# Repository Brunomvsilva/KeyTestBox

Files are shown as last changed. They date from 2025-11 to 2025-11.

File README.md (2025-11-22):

# KeytestBox

_Embedded platform designed to integrate automotive HMI key-testing systems in production environments._

_This project was developed at Preh Portugal as part of my Master’s thesis._

---

## Preview

<table align="center">
  <tr>
    <td align="center">
      Real PCB Photo<br>
      <em>Real KeytestBox Image</em>
    </td>
    <td align="center">
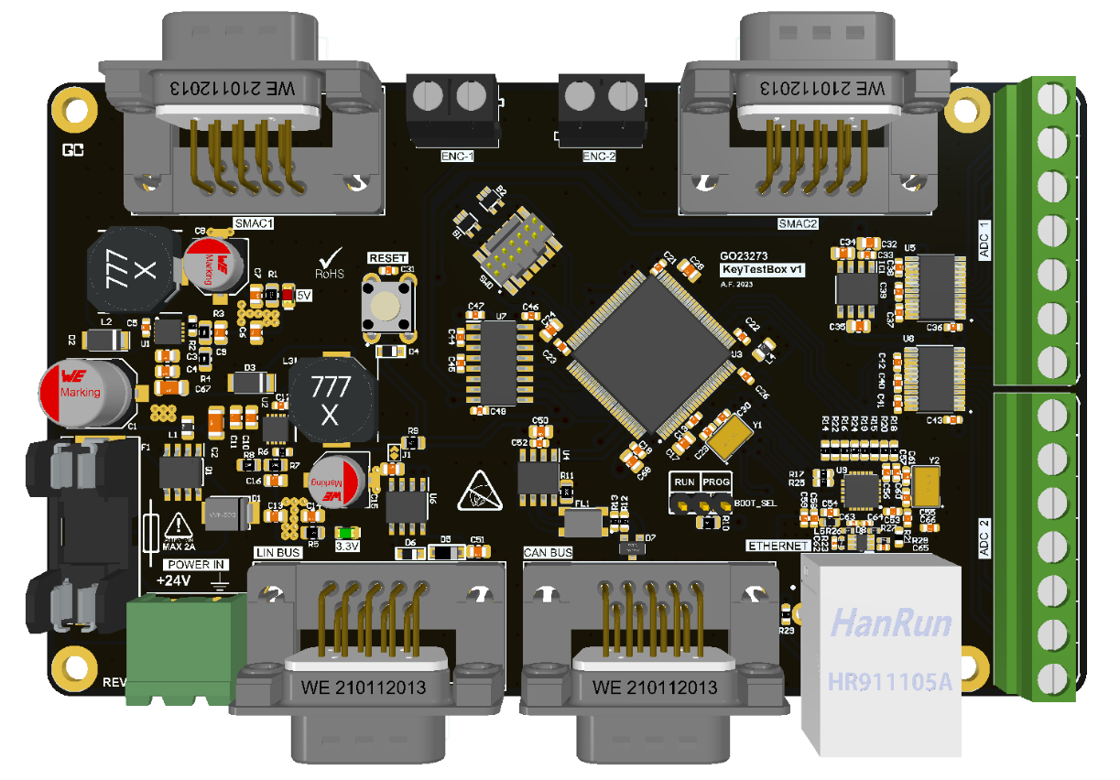
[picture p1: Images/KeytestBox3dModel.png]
3D Model of KeyTestBox
      <br>
      <em>3D model of the KeyTestBox enclosure</em>
    </td>
  </tr>
</table>

---

## Table of Contents

- [Introduction](#introduction)
- [Typical Key Test Output](#typical-key-test-output)
- [Incremental vs Continuous Tests](#incremental-vs-continuous-tests)
  - [Incremental Tests](#incremental-tests)
  - [Continuous Tests](#continuous-tests)
- [Problem Statement](#problem-statement)
  - [Problem 1: Delay via CAN/LIN](#problem-1-delay-when-reading-uut-data-via-can-or-lin)
  - [Problem 2: Low resolution and missed events](#problem-2-low-resolution-and-missed-events-in-incremental-tests)
  - [Consequence](#consequence-forced-to-use-expensive-continuous-test-systems)
- [Solution, Main Goals and Requirements](#solution-main-goals-and-requirements)
  - [Main Goals](#main-goals)
  - [Hardware Requirements](#hardware-requirements)
  - [Software Requirements](#software-requirements)
- [Hardware Overview](#hardware-overview)
- [Final Hardware](#final-hardware)
- [Software and Tools Used](#software-and-tools-used)
- [MQTT Commands Implemented](#mqtt-commands-implemented)
- [Tests and Results](#tests-and-results)
  - [UUT Lever and Testbench Setup](#uut-lever-test-and-testbench-setup)
  - [Sampling and Performance](#sampling-and-performance)
- [Conclusion](#conclusion)
- [Skills Learned](#skills-learned)

---

## Introduction 

Automotive HMI, such as climate and central control panels, rely on high-quality tactile feedback. **Force–displacement** key tests quantify that feel essencially by measuring the relation between **applied force** and **key travel**.

Images below display the **main components** of a key test system

<div align="center">
<table>
  <tr>
    <td style="padding-right: 40px;">
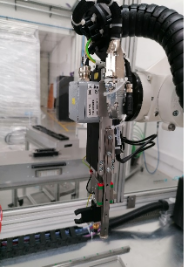
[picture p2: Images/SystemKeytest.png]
      
    </td>
    <td style="padding-left: 40px;">
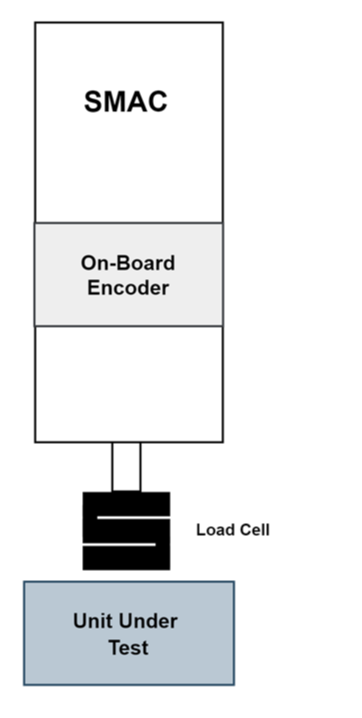
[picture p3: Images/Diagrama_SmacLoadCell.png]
      
    </td>
  </tr>
</table>
</div>

### During a test:
- The key is pressed by a **SMAC linear motor**  
- **Force** is measured using a **load cell with an amplifier**  
- **Key travel (displacement)** is obtained from the **SMAC internal encoder**  
- The **Unit Under Test (UUT)** sends data via **CAN/LIN** during the test, such as:  
  - **Key state (pressed / released)**
  - **Lever position or angle** (e.g. gear selector tests)  
  - **Selected gear value**  
  - **UUT Hall sensors or internal position data**  
  - Other diagnostic or status information

### Typical Key Test Output

The **Force–Displacement** curve is the most common way to characterize how a key or button behaves when it is pressed and released. It represents the force applied to the key as a function of its travel (displacement).

<p align="center">
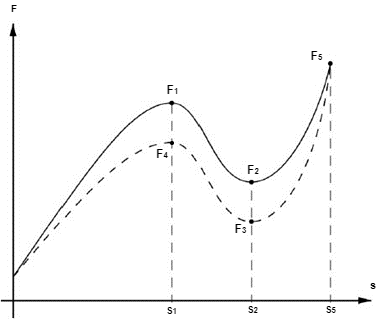
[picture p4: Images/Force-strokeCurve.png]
  
</p>

Curves differ depending on the type of key being tested.
During a test, the key is pressed (force increases) until it reaches a maximum point, and then released. From this curve, mechanical parameters of the key can be extracted:

| Symbol | Description |
|---|---|
| **S1** | Displacement at which the key actuates (snap/collapse point). |
| **F1** | Actuation force – force required to trigger the snap of the membrane or key mechanism at S1. |
| **S2** | Displacement where electrical contact occurs with the PCB. |
| **F2** | Contact force – minimum force required to close the electrical contact at S2. |
| **F3** | Return force – force at which the electrical contact is released during the return movement. |
| **F4** | Force difference between actuation and release states. |
| **F5** | Maximum applied force during the test (should not exceed mechanical limits). |
| **Ss** | Maximum travel / end of mechanical stroke. |

One of the most important metrics derived from this curve is the **Snap Ratio (SR)**, which indicates how strong the tactile feedback is:

$$
SR=\dfrac{F_1-F_2}{F_1}\times 100\%
$$

- A higher **Snap Ratio** = stronger tactile feedback (more noticeable “click”).
- A lower **Snap Ratio** = softer feedback, which may feel smoother but less perceptible.
- Ideal **SR** values depend on the application.

---

## Incremental vs Continuous Tests

The flowcharts below provide a simplified comparison between the two testing methods.  
The main difference is that in **Incremental Tests**, the actuator stops at each step to acquire a sample, while in **Continuous Tests**, the actuator moves without stopping and data is sampled in real time.

<table align="center">
  <tr>
    <td align="center">
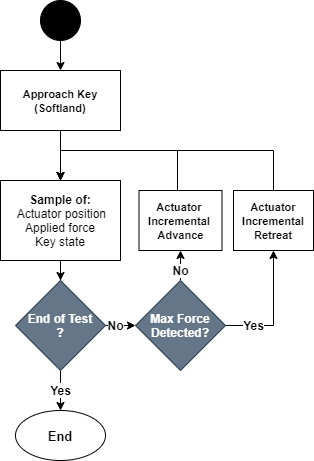
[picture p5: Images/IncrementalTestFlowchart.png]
      <br>
      <em>Incremental Test Flowchart</em>
    </td>
    <td align="center">
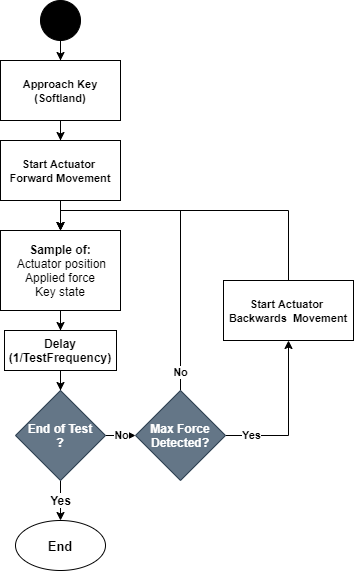
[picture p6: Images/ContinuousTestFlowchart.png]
      <br>
      <em>Continuous Test Flowchart</em>
    </td>
  </tr>
</table>

---

## Incremental Tests

### Incremental Test System Example (without the KeyTestBox)

<p align="center">
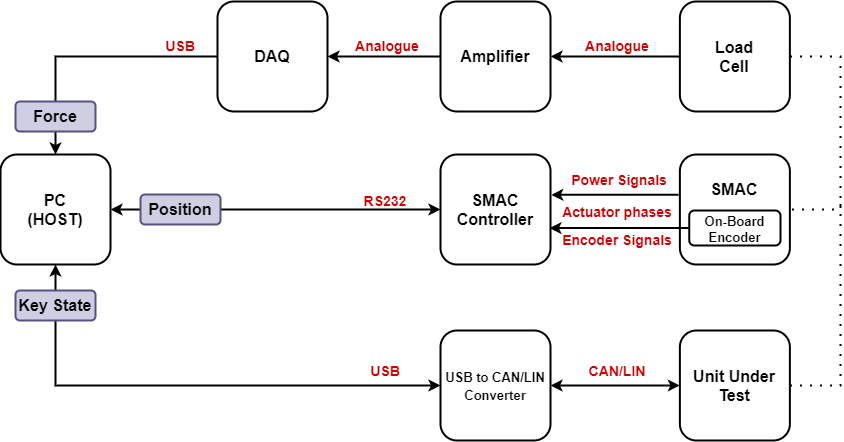
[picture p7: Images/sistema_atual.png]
Current System Architecture
  
</p>

- **Force** data is acquired by the host PC via a USB Data Acquisition (DAQ) device from National Instruments.
- **Position** data is acquired by RS232 from the actuator controller
- **Key State or info** data is acquired through a CAN/LIN-USB converter

### Advantages:
- Low cost
- Easier to implement

### Disadvantages
- **low test resolution** (low sample density)
- May miss the sampling of the **snap point**, especially on **short-travel keys**
- Can fail to meet client requirements

### Incremental Test Output Example

<p align="center">
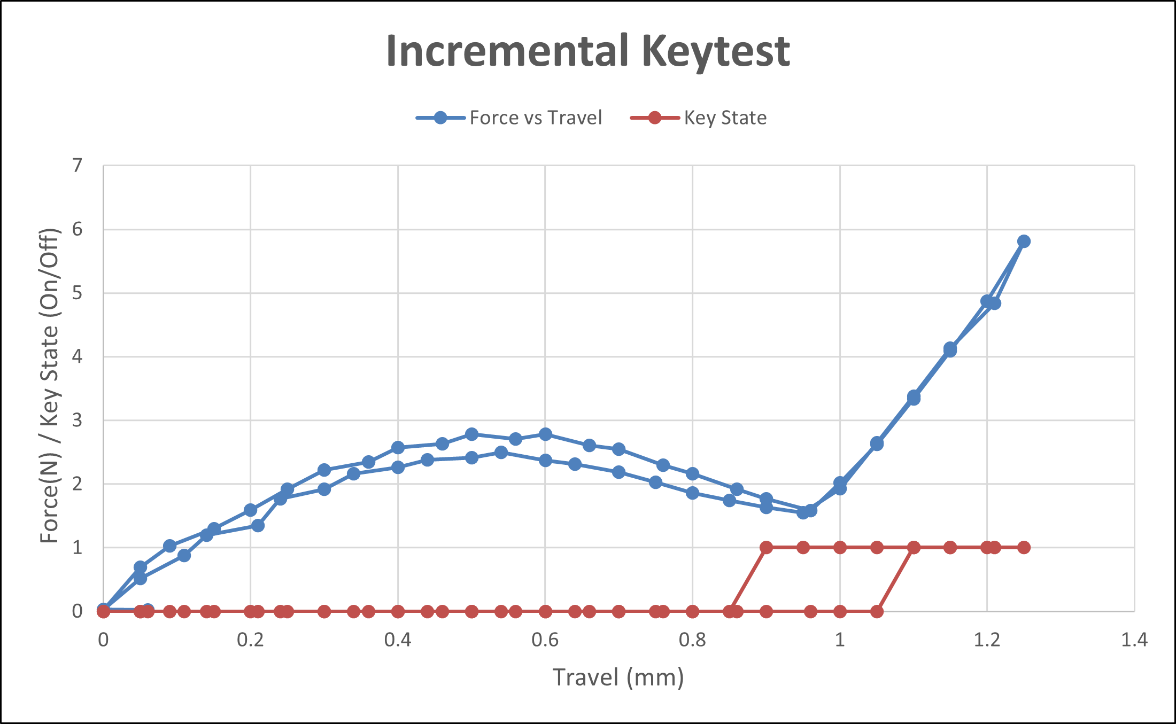
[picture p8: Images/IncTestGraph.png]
Inc Test Graph
  
</p>

---

## Continuous Tests

### Continuous Test System (Without KeyTestBox)

<p align="center">
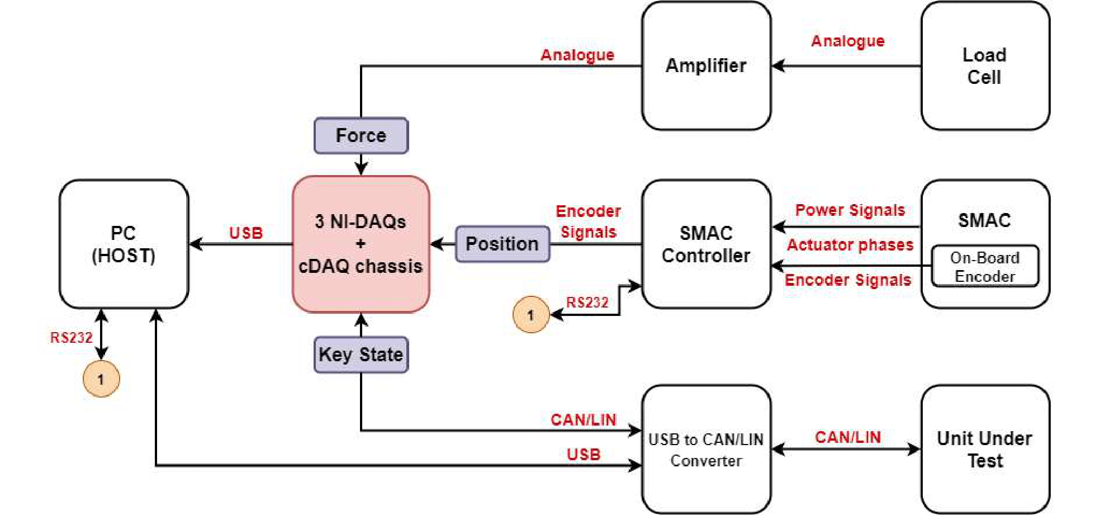
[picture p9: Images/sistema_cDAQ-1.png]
Continuous Test System
  
</p>

In continuous testing, the actuator **moves without stopping**, and all signals are sampled in real time. This enables a smoother force–displacement curve and higher data accuracy.

- **Force** is measured by a load cell and continuously acquired via the DAQ system  
- **Position (travel)** is obtained from the SMAC actuator encoder in real time  
- The **Unit Under Test (UUT)** transmits its state (CAN/LIN), such as key/lever status or sensor values, during movement  
- All data is timestamped and saved by the DAQ system for later processing  

> While this setup delivers high accuracy and resolution, it uses sophisticated hardware and is **significantly more expensive**.

### Advantages
- **High sample density** → more precise force–travel curve  
- **Accurate snap detection**  
- **Faster test execution** → important in industrial production environments  

### Disadvantages
- **Substantially higher cost** due to DAQ modules and synchronization hardware.

### Continuous Test Output Example

<p align="center">
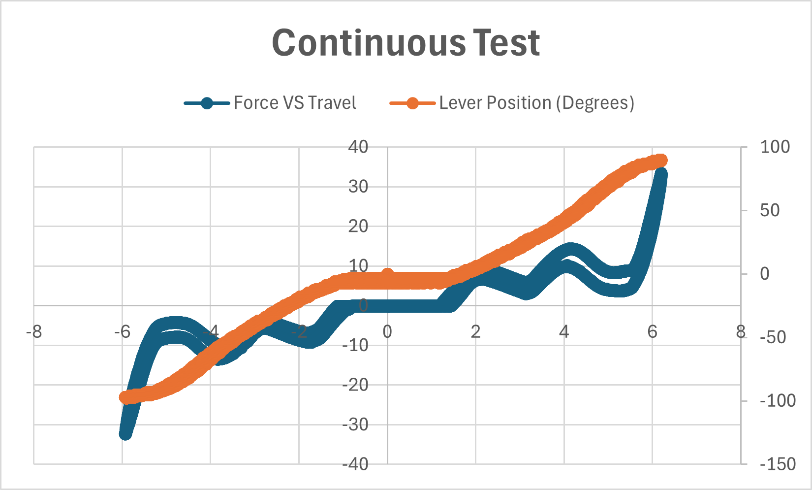
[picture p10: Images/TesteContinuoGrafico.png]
Continuous Test Graph
  
</p>

---

## Problem Statement

In industrial test setups, especially for testing mechanical keys, the most common approach is the **incremental test method**. This approach is simple and cost-effective, and it can work well in many cases.

However, **in several real-world situations, incremental testing is not sufficient or may not work at all**. These limitations arise due to the way the test equipment communicates and the type of measurements required:

---

### Problem 1: Delay when reading UUT data via CAN or LIN

Many devices under test (UUTs) only report their internal state (e.g., whether a button is pressed or not) when the host explicitly **requests the data** using a communication protocol like **CAN** or **LIN**. This process introduces a delay between the request and the response.

If the actuator is moving during this time (as in a continuous test), by the time the host receives the data, the key is already in a **different position**, and the measured force has also changed. This causes a mismatch between the **key state**, **position**, and **force**, making the data unreliable.

<p align="center">
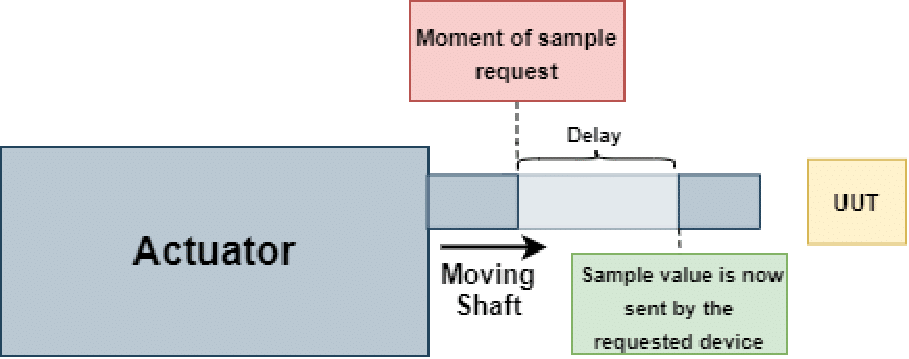
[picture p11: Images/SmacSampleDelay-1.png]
Sampling delay during continuous motion (request/response CAN/LIN)
  
</p>

---

### Problem 2: Low resolution and missed events in incremental tests

Given the problem 1, a good solution would be to **stop the actuator** and only then **request the data via CAN or LIN**, then wait for the response.  
However, as said before, **incremental testing has limited resolution**. Since the actuator only samples at discrete steps, fast or short events — such as the **snap point** (a sudden change in force when pressing a key) — may occur between two sample points and go undetected.

This is particularly problematic for **short-travel keys**, where the full keypress happens in a very small movement range. In such cases, a small number of samples is not enough to capture the key’s behavior accurately.

---

### Consequence: Forced to use expensive continuous test systems

To solve these problems, test stations often switch to **continuous testing**, which are significantly more expensive

---

## Solution, Main Goals and Requirements

To overcome the limitations of incremental testing and avoid the high cost of commercial continuous testing systems, a new solution is required — one that enables **real-time, synchronized testing** without the complexity and price of traditional DAQ systems.

The **KeyTestBox** is proposed as a **low-cost**, **modular**, and **reusable** platform suitable for production testing environments.

### Main Goals 

- **Real-time acquisition** of:
  - **Force** (via load cell)
  - **Position** (via SMAC encoder)
  - **UUT data** (via CAN or LIN protocols)

### Hardware Requirements

- 24 VDC power supply  
- CAN interface (supports baud rate up to 1 Mbps)  
- LIN interface (supports baud rate up to 19 200 bps)  
- Ethernet port (10/100 Mbps)  
- Two RS232 interfaces  
- Minimum of five differential analog inputs (−10 V to +10 V) **(Mainly to read the 2 Load Cells but some extra were added)**  
- Two linear encoder counters  
- Microcontroller-based system
- PCB design

---

### Software Requirements

- Firmware developed in C
- Start and stop a test routine upon request  
- Ability to export the acquired test data  
- Capability to execute external commands during the test routine  
- Use of the MQTT protocol for communication with the host  

---

## Hardware Overview

<p align="center">
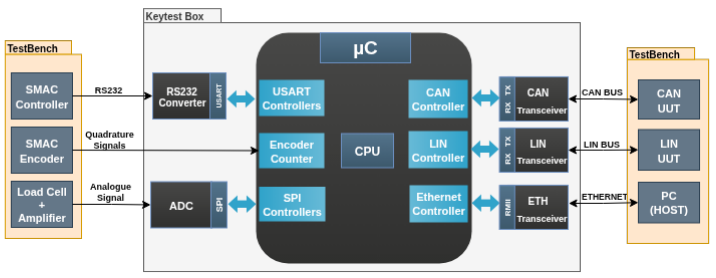
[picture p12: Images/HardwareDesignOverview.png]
overviewHardware
  
</p>

---

## Final Hardware

[Full **Hardware Schematic**](PCB/keytestbox_schematic.pdf)

### Main Components

- STM32F767VIT6
- LAN8742A
- 2x MAX1032 (ADC)
- MCP2021 (LIN)
- MCP2551 (CAN)
- MAX232 (RS232 Converter) 
- STLINK-V3 Debugger SWD
 
<table align="center">
  <tr>
    <td align="center">
      Real PCB Photo<br>
      <em>Real KeytestBox Image</em>
    </td>
    <td align="center">
      3D Model of KeyTestBox<br>
      <em>3D model of the KeyTestBox enclosure</em>
    </td>
  </tr>
</table>

> PCB Schematic done by me in KiCad
> PCB Layout was designed by another company
---

## Software and Tools used

- STM32Cube IDE
- FreeRTOS
- LwIP IP Stack
- Mosquitto MQTT
- Percepio Tracealyzer

---

## MQTT Commands Implemented

<p align="center">
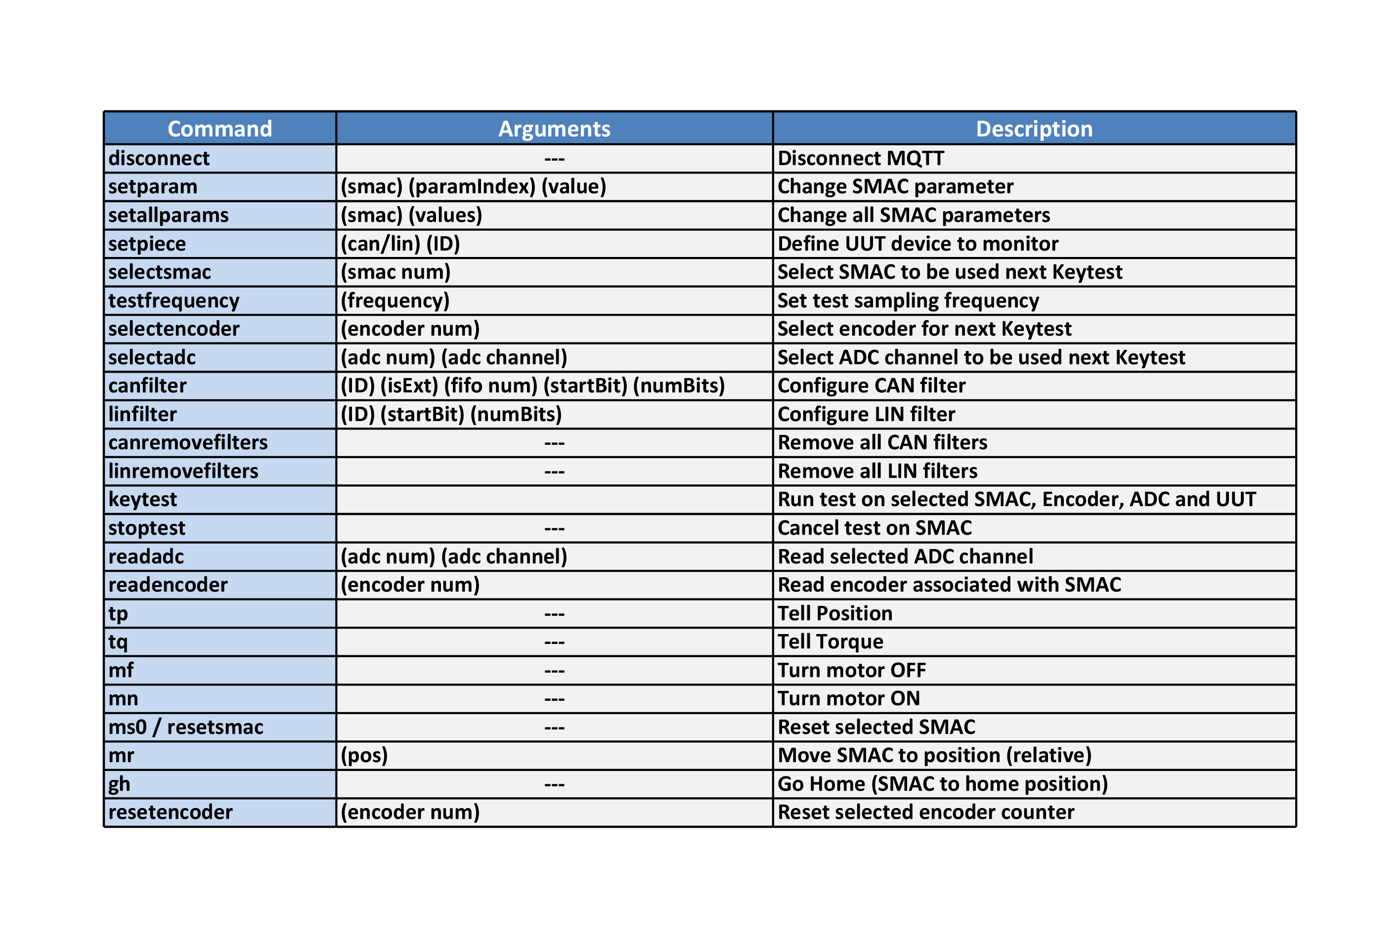
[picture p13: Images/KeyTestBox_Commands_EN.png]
MQTT Commands
  
</p>

---

## Tests and Results

The primary test target was a **gear shift lever** from the UUT shown below. This lever represents one of the most challenging components to test due to several factors:

- The lever travel is **approximately 12 mm**, much longer than typical pushbuttons (≈ 3 mm).
- Each test cycle includes **two snap events** in each direction (forward and return).
- The UUT transmits a **high volume of CAN data** during movement, requiring reliable high-frequency acquisition and synchronization.

### UUT Lever Test and Testbench Setup

<p align="center">
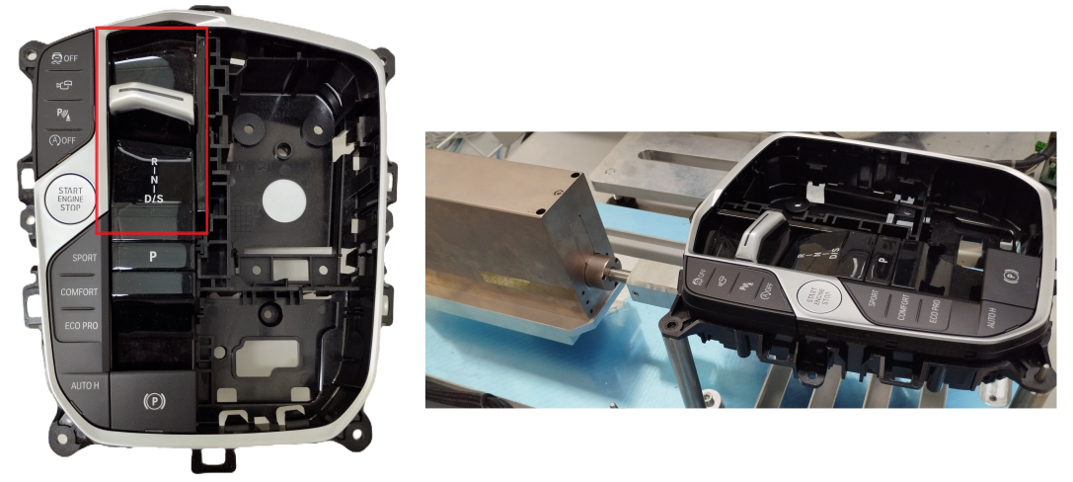
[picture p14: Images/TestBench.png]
TB setup
  
</p>

The figure highlights the tested lever in red and shows the complete testbench used.

---

### Sampling and Performance

Tests were conducted at various sampling frequencies. The system successfully performed synchronized data acquisition at rates **up to 3000 Hz**, capturing:

- **Force data** via load cell  
- **Position data** from the SMAC actuator encoder  
- **Key state data** via CAN from the UUT

This sampling rate proved sufficient for accurate detection of all snap points and detailed force-position profiles.

> Increasing the frequency beyond 3000 Hz was not necessary and led to **excessive data**, which becomes impractical to store locally due to **RAM constraints**.

### Test Result Graph @3000Hz + Lever Position 

<p align="center">
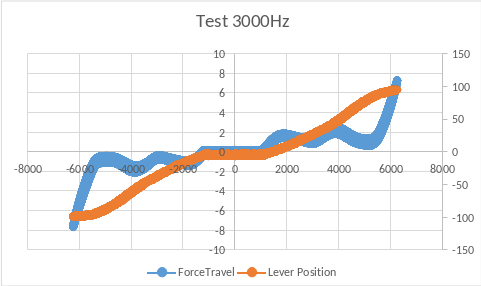
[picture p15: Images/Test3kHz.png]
test3khz
  
</p>

### Test Result Graph @1250Hz + Gear Selected

<p align="center">
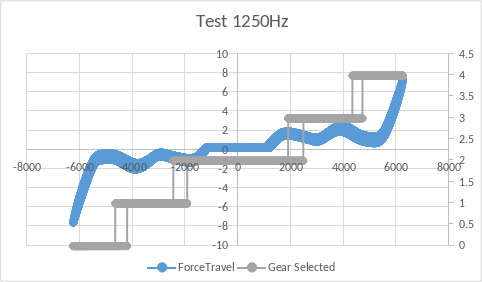
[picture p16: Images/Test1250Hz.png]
Test1250hz
  
</p>

---

## Conclusion

All the defined requirements were met.
Furthermore, the tests demonstrated that the KeyTestBox platform is fully capable of performing continuous key testing with:

- High-resolution data acquisition up to **3000 Hz**
- Data synchronization
- Successful operation even on demanding UUT test cases

> The **KeyTestBox achieved a cost reduction of approximately 91.75%**, lowering the price about 12 times comparing to the other solution

> One limitation was the available RAM, which is sufficient for most use cases. However, for UUTs that transmit **large volumes of CAN data**, it may be necessary to **select only the relevant CAN/LIN UUT data** to avoid memory overflow.  
>  
> If full data capture is required, this limitation can easily be addressed by using a **microcontroller with more RAM**, for example STM32H7 family.

---

## Skills Learned

This project provided practical experience in the design and implementation of a **cyber-physical embedded system** for industrial testing applications.

### General Skills
- **Real-Time Embedded Systems**
- **Cyber-Physical System Design**  
- **Signal and Data Acquisition**
- **Cost–Performance Trade-Offs**

### Technical Skills
- **Embedded C (STM32)**
- **FreeRTOS task design**
- **Peripheral integration** — SPI, UART, ADC, CAN, LIN, Encoders, Timers
- **Networking with LwIP + MQTT**
- **PCB schematic design (KiCad)**

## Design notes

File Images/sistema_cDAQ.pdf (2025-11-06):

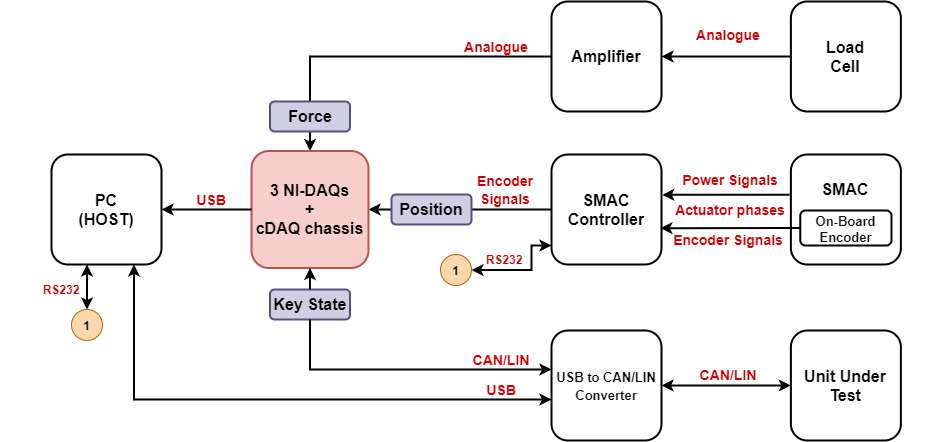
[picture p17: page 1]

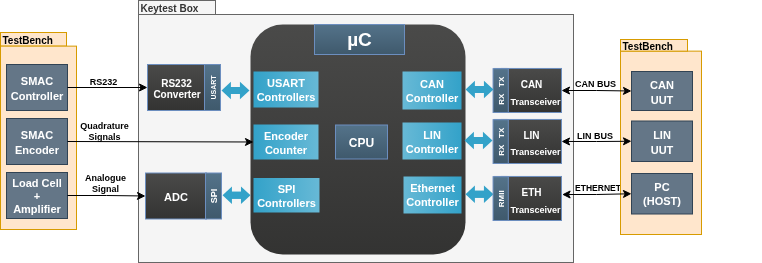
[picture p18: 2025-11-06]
Images/HardwareDesign.png

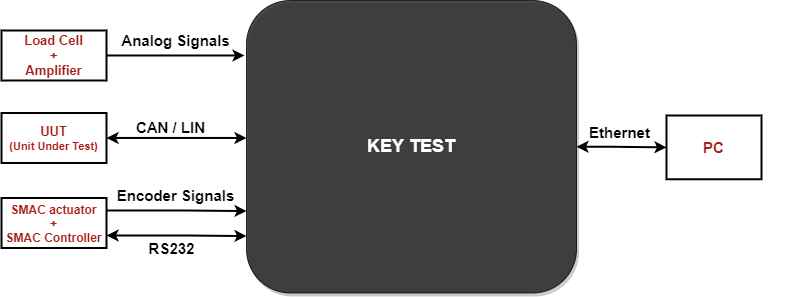
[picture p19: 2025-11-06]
Images/sistema_overview.png

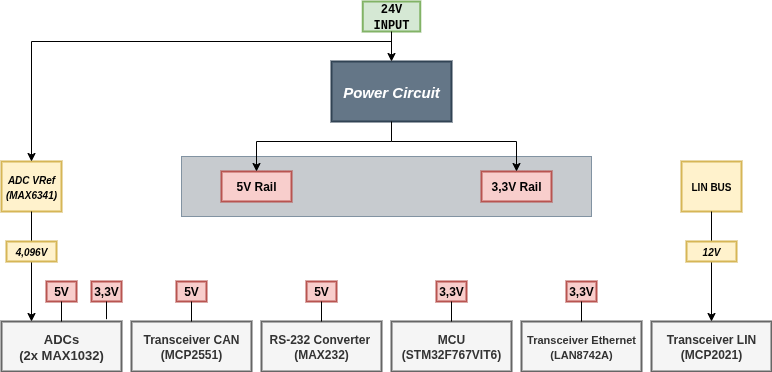
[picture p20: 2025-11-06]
Images/PowerCircuitDesign.png

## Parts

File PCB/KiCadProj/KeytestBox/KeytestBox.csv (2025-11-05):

Reference | Qty | Value | DNP | Exclude from BOM | Exclude from Board | Footprint | Datasheet
C1,C20,C22,C23,C24,C26,C27,C31,C36,C37,C39,C45,C46,C48,C49,C50,C53,C54,C55,C56,C58,C59,C60,C61,C63,C64 | 26 | 100nF 16V X7R |  |  |  |  | ~
C2 | 1 | 100uF 35V |  |  |  |  | ~
C3,C4 | 2 | 22uF 35V X5R |  |  |  |  | ~
C5,C6,C7,C8,C13,C14,C15,C16,C62 | 9 | 10uF 35V X5R |  |  |  |  | ~
C9,C10 | 2 | 470nF X7R |  |  |  |  | ~
C11,C12 | 2 | 10pF X7R |  |  |  |  | ~
C17,C18 | 2 | 47uF 35V |  |  |  |  | ~
C19 | 1 | 4.7uF 16V X5R |  |  |  |  | ~
C21,C25 | 2 | 12pF 16V NP0 |  |  |  |  | ~
C28,C29 | 2 | 2.2uF 16 V X5R |  |  |  |  | ~
C30,C35,C51 | 3 | 1uF 16V X5R |  |  |  |  | ~
C32,C33 | 2 | 27pF 16V NP0 |  |  |  |  | ~
C34 | 1 | 470pF 16V X7R |  |  |  |  | ~
C38 | 1 | 10uF 16V X7R |  |  |  |  | ~
C40,C57 | 2 | 10uF 16V X5R |  |  |  |  | ~
C41,C42,C43,C44 | 4 | 10pF 50V X7R |  |  |  |  | ~
C47,C52 | 2 | 2.2uF 16V X5R |  |  |  |  | ~
D1 | 1 | SMBJ30CA-13-F
D2,D3 | 2 | PMEG3050EP |  |  |  |  | ~
D4 | 1 | 5V |  |  |  | LED_SMD:LED_1206_3216Metric | http://www.everlight.com/file/ProductFile/IR26-21C-L110-TR8.pdf
D5 | 1 | 3.3V |  |  |  | LED_SMD:LED_1206_3216Metric | http://www.everlight.com/file/ProductFile/IR26-21C-L110-TR8.pdf
D6 | 1 | CDSOD323-T05C |  |  |  |  | ~
D7 | 1 | SP3002-04JTG
D8 | 1 | PTVS43VS1UR115 |  |  |  | Diode_SMD:Nexperia_DSN1608-2_1.6x0.8mm | https://assets.nexperia.com/documents/data-sheet/PTVS5V0Z1USK.pdf
D9 | 1 | ESDLIN1524BJ |  |  |  | Diode_SMD:ST_D_SMC | https://www.st.com/resource/en/datasheet/sm15t36a.pdf
F1 | 1 | 1A5 |  |  |  |  | ~
FB1,FB2 | 2 | BLM21SP601SH1D |  |  |  |  | ~
FB3 | 1 | BLM18PG121SN1D |  |  |  |  | ~
FL1 | 1 | ACT45B-510-2P-TL003 |  |  |  |  | ~
IC1,IC2 | 2 | LT3991EMSE#PBF |  |  |  | SOP50P490X110-11N | https://datasheet.datasheetarchive.com/originals/distributors/Datasheets-SFU4/DSASF4000-3355.pdf
J1 | 1 | ADC_1 |  |  |  |  | ~
J2 | 1 | ADC_2 |  |  |  |  | ~
J3 | 1 | SMAC1 |  |  |  |  | ~
J4 | 1 | SMAC2 |  |  |  |  | ~
J5 | 1 | POWER IN
J6 | 1 | CAN BUS |  |  |  |  | ~
J7 | 1 | LIN BUS |  |  |  |  | ~
J8 | 1 | ENCODER 1
J9 | 1 | ENCODER 2
J10 | 1 | HR911105A |  |  |  | HR911105A:HANRUN_HR911105A
L1,L2 | 2 | MSS1038-103NLC |  |  |  |  | ~
MH1,MH2,MH3,MH4 | 4 | 3mm |  | Excluded from BOM |  |  | ~
Q1 | 1 | SI4403CDY-Y1-GE3 |  |  |  | DIODE3_DESD1CAN2SOQ-7_DIO | DMP3056L-7
R1,R2 | 2 | 118kΩ 1% |  |  |  |  | ~
R3,R6 | 2 | 1MΩ 1% |  |  |  |  | ~
R4 | 1 | 309kΩ 1% |  |  |  |  | ~
R5 | 1 | 1M78Ω 1% |  |  |  |  | ~
R7,R8 | 2 | 330Ω |  |  |  |  | ~
R9,R10,R15,R16,R17,R18,R19,R20 | 8 | 10kΩ 5% |  |  |  |  | ~
R11,R12,R13,R14 | 4 | 33Ω 1% |  |  |  |  | ~
R21,R22 | 2 | 300Ω 1% |  |  |  |  | ~
R23 | 1 | 12k1Ω 1% |  |  |  |  | ~
R24,R25,R26,R27 | 4 | 49.9Ω 1% |  |  |  |  | ~
R28 | 1 | 100kΩ 5% |  |  |  |  | ~
R29 | 1 | 120Ω 1% |  |  |  |  | ~
STLINK1 | 1 | STLINK/V3
SW1 | 1 | BOOT_SEL |  |  |  | Button_Switch_SMD:Nidec_Copal_CAS-120A | https://www.nidec-components.com/e/catalog/switch/cas.pdf
SW2 | 1 | RESET |  |  |  | Reset_BTN:SW_1825910-6-4 | http://www.apem.com/int/index.php?controller=attachment&id_attachment=1371
U1,U2 | 2 | ESDALC6V1W5 |  |  |  | Package_DFN_QFN:DFN-6-1EP_2x1.6mm_P0.5mm_EP1.15x1.3mm
U3 | 1 | STM32F767VIT6 |  |  |  | Package_QFP:LQFP-100_14x14mm_P0.5mm | https://www.st.com/resource/en/datasheet/stm32f767vi.pdf
U4 | 1 | LAN8742A-CZ-TR |  |  |  | Package_DFN_QFN:VQFN-24-1EP_4x4mm_P0.5mm_EP2.5x2.5mm_ThermalVias | http://ww1.microchip.com/downloads/en/DeviceDoc/8742a.pdf
U5 | 1 | MAX6341CSA+ |  |  |  | 21-0041B_8_MXM | MAX6341CSA+
U5A1,U6A1 | 2 | MAX1032BEUG+ |  |  |  | 21-0066J_24_MXM | max1032beug+
U6 | 1 | MAX232ACSE+ |  |  |  | MAX232A:21-0041_S16&plus_1_MXM | MAX232ACSE+
U7 | 1 | MCP2551-I-SN |  |  |  | Package_SO:SOIC-8_3.9x4.9mm_P1.27mm | http://ww1.microchip.com/downloads/en/devicedoc/21667d.pdf
U8 | 1 | MCP2021-330E/SN |  |  |  | Package_SO:SOIC-8_3.9x4.9mm_P1.27mm
U9 | 1 | ESD2CAN24DBZRQ1
Y1 | 1 | ECS-160-12-30BQ-ADS-TR |  |  |  |  | ~
Y2 | 1 | FL2500213Z |  |  |  |  | ~

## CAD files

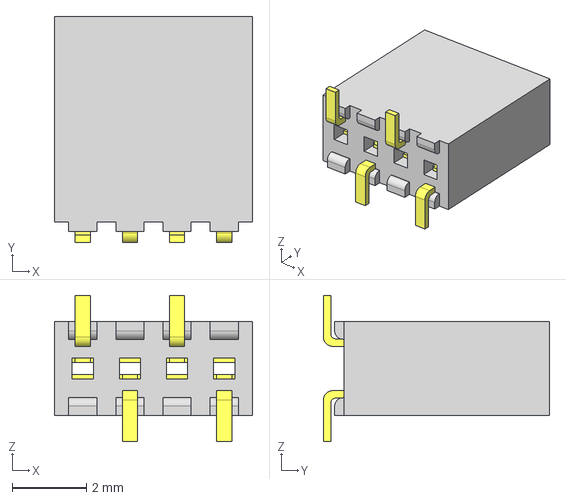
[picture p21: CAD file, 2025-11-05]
PCB/KiCadProj/KeyTestBoxLib/4PIN_CONN/RSM-104-02-T-S.step
5.33 x 6.10 x 3.94 mm
C-64-02-04-S
RSM-104-02-S_socket

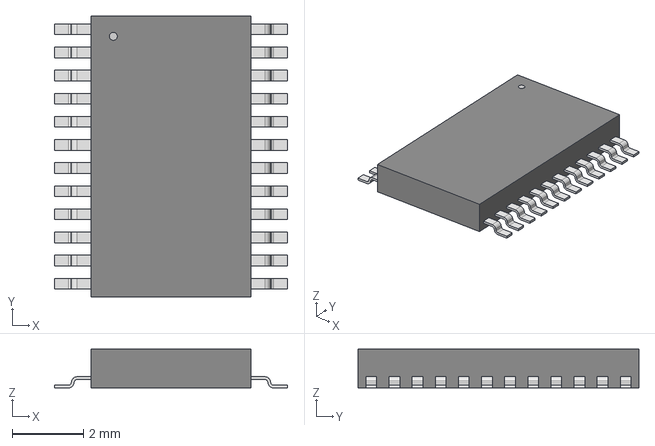
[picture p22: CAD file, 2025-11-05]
PCB/KiCadProj/KeyTestBoxLib/ADC_MAX1032/21-0066J_24_MXM.step
6.55 x 7.90 x 1.09 mm

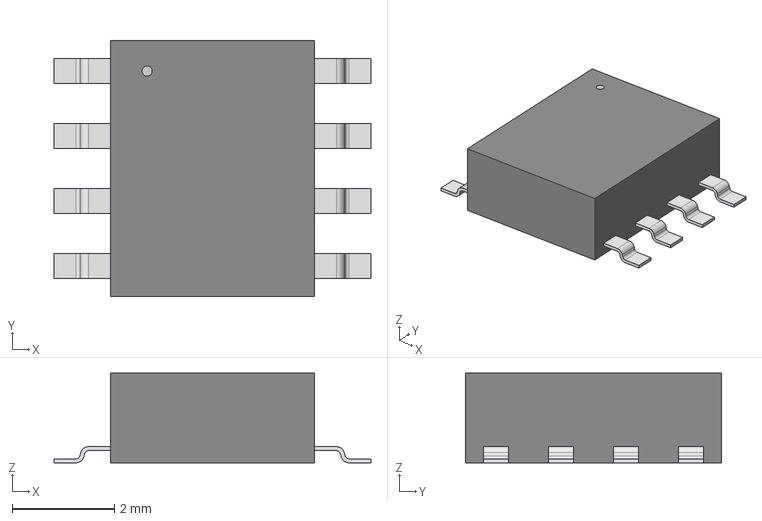
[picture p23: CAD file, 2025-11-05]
PCB/KiCadProj/KeyTestBoxLib/ADC_VREF_MAX6341/21-0041B_8_MXM.step
6.20 x 5.00 x 1.75 mm

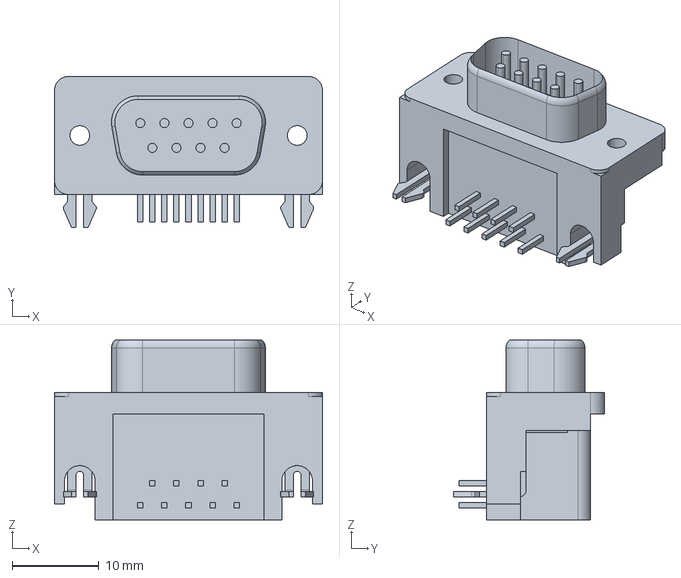
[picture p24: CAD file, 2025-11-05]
PCB/KiCadProj/KeyTestBoxLib/Conector DB9/STEP/c-2301843-1-b-3d.stp
30.8 x 17.4 x 20.6 mm

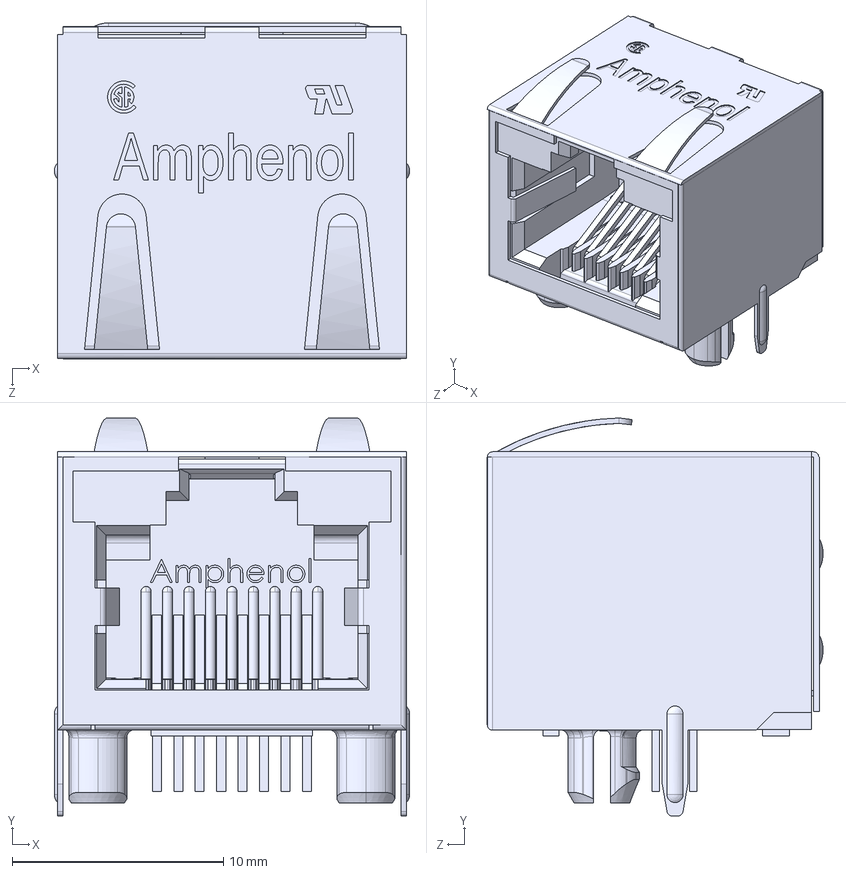
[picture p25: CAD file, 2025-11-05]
PCB/KiCadProj/KeyTestBoxLib/Conector Eth2/RJHSE-5384.step
16.8 x 18.8 x 15.9 mm

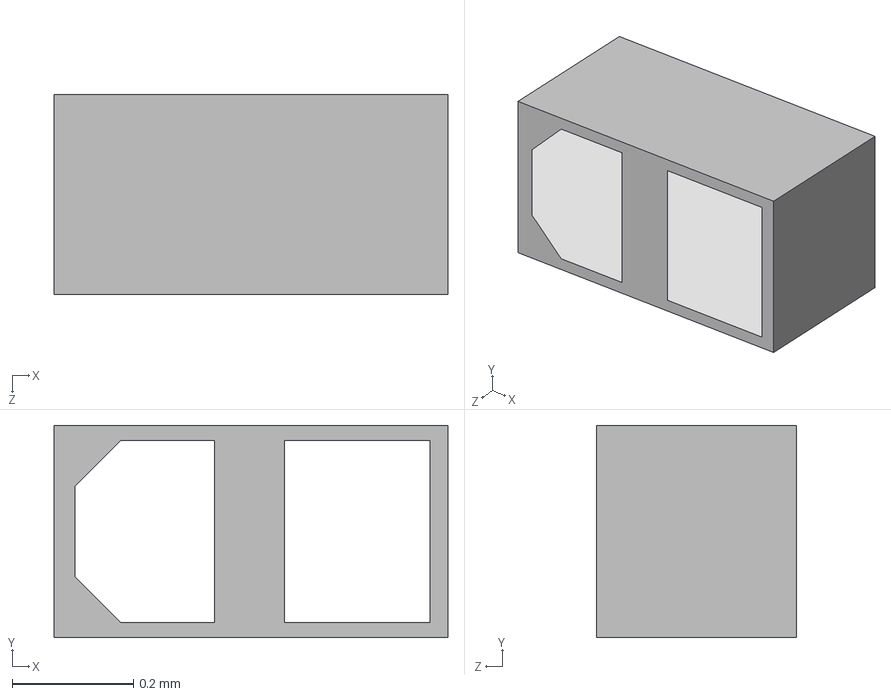
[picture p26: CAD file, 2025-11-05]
PCB/KiCadProj/KeyTestBoxLib/Diodos/ESDALC6V1-1U2/3D/ESDALC6V1-1U2.stp
0.65 x 0.35 x 0.33 mm

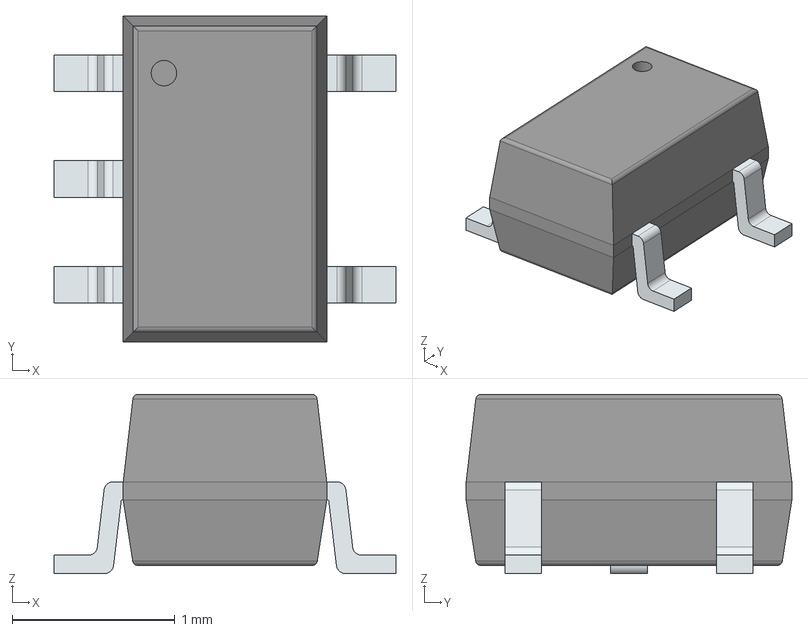
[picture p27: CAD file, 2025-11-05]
PCB/KiCadProj/KeyTestBoxLib/Diodos/ESDALC6V1W5/3D/ESDALC6V1W5.stp
2.10 x 2.00 x 1.10 mm
PinsArrayL
PinsArrayR

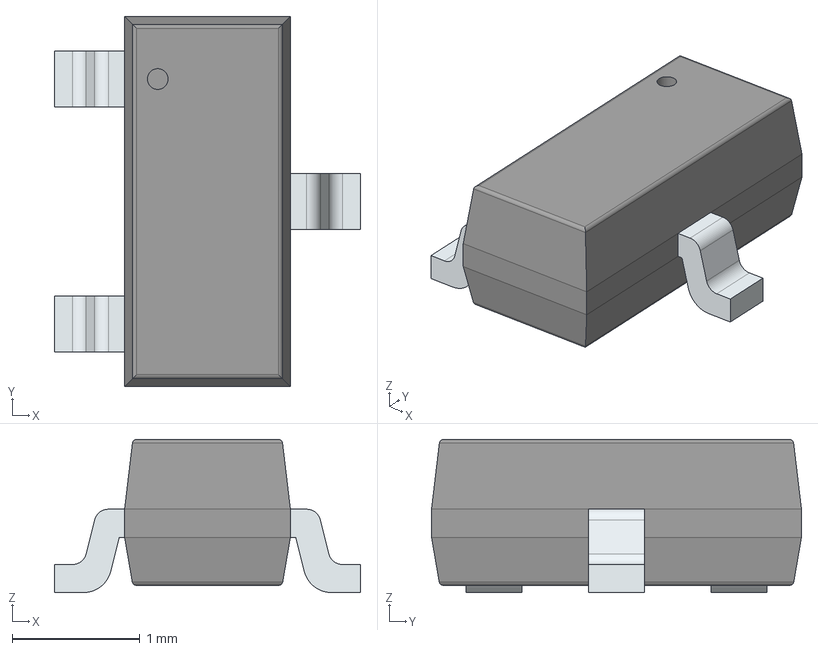
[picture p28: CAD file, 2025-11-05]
PCB/KiCadProj/KeyTestBoxLib/Diodos/MMBZ27VCL/MMBZ27VCL-7-F/3D/MMBZ27VCL-7-F.stp
2.40 x 2.90 x 1.20 mm
PinsArrayL
FilletPinR

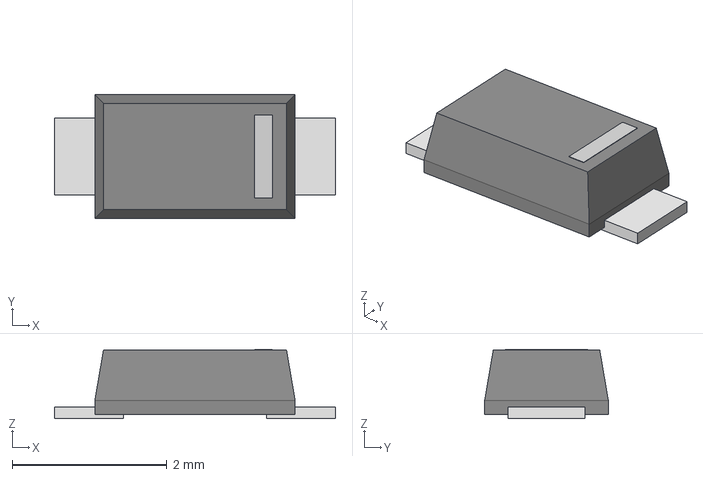
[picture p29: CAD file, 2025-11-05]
PCB/KiCadProj/KeyTestBoxLib/Diodos/RBR2MM40ATR/DIO_RB051MM_ROM.step
3.63 x 1.60 x 0.895 mm

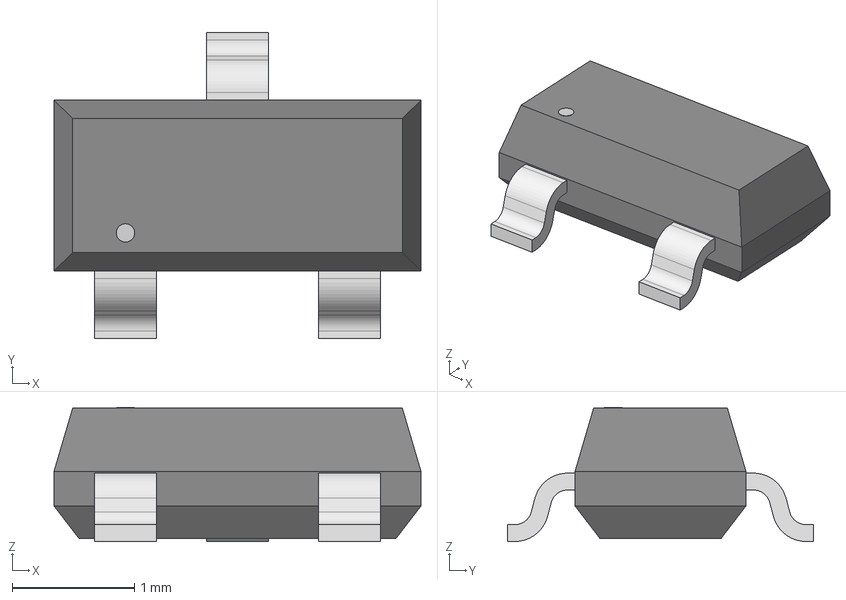
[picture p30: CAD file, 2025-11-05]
PCB/KiCadProj/KeyTestBoxLib/DMP3056L-7/DIODE3_DESD1CAN2SOQ-7_DIO.step
3.00 x 2.50 x 1.09 mm

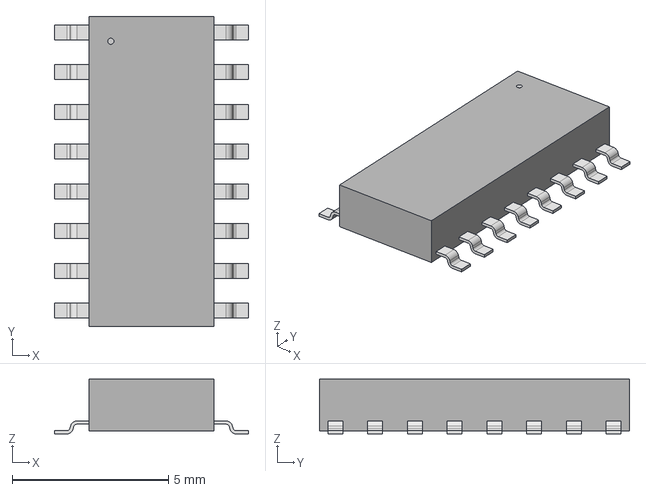
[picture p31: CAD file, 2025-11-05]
PCB/KiCadProj/KeyTestBoxLib/MAX232A/21-0041_S161_MXM.step
6.20 x 9.91 x 1.75 mm

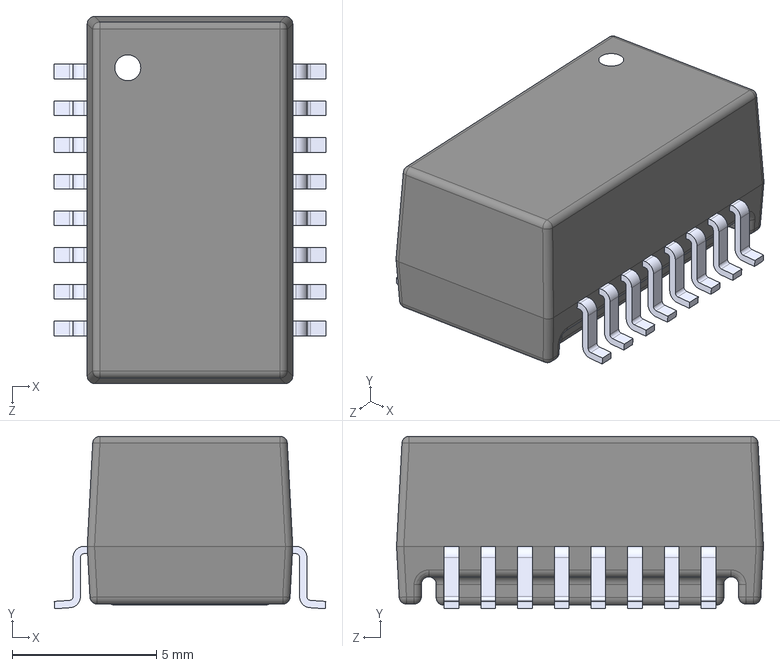
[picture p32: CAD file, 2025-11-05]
PCB/KiCadProj/KeyTestBoxLib/Network transformer/H2019NLT.step
9.40 x 5.97 x 12.7 mm

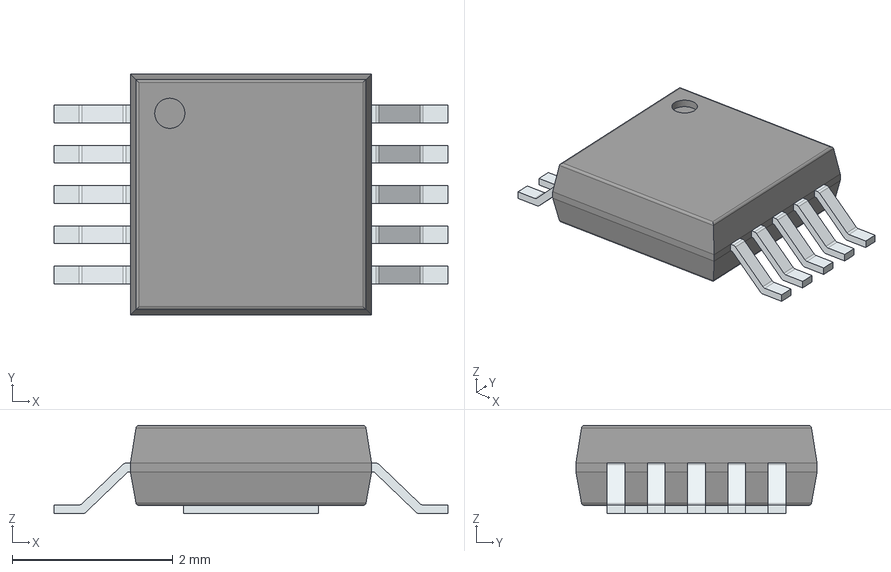
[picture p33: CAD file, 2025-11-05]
PCB/KiCadProj/KeyTestBoxLib/STEPDOWN_Buck_Converter/LT3991EMSE#PBF/3D/LT3991EMSE#PBF.stp
4.90 x 3.00 x 1.10 mm
PinsArrayLR
ThermalPad

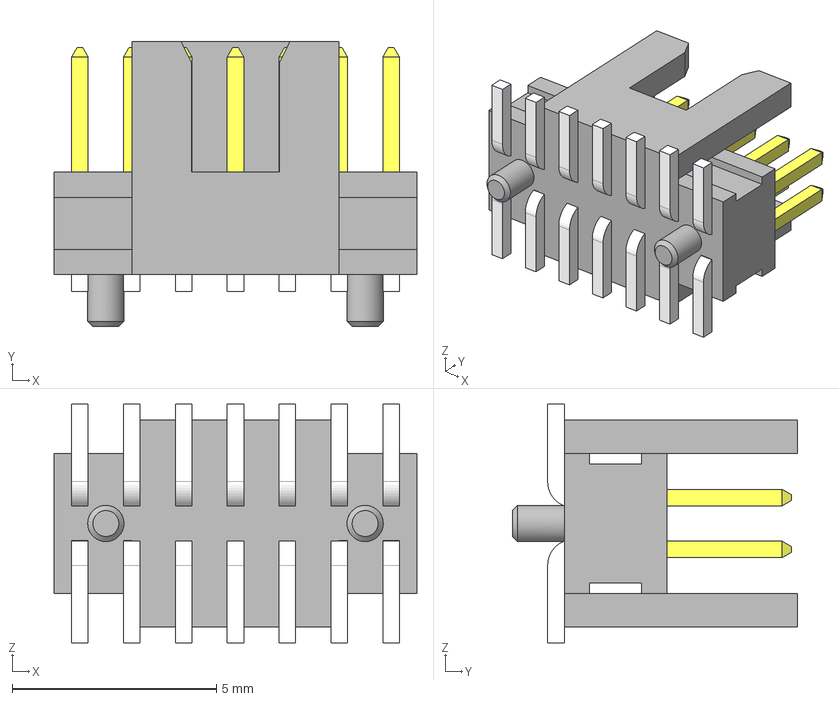
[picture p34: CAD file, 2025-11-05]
PCB/KiCadProj/KeyTestBoxLib/SWD_CONN/FTSH-107-01-L-DV-K-A.step
8.89 x 6.98 x 5.84 mm
FTSH-107-01-L-DV-K-A_pins2
FTSH-107-01-L-DV-K-A_pins1
FTSH-107-01-L-DV-K-A_body

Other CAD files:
PCB/KiCadProj/KeyTestBoxLib/Switch/EG1218.step
PCB/KiCadProj/KeyTestBoxLib/USBLC6-4SC6/SOT23-6L_STM.step
PCB/KiCadProj/KeyTestBoxLib/2PIN_SCREW_CONN/282837-2.step
PCB/KiCadProj/KeyTestBoxLib/7PIN_SCREW_CONN/282837-7/3D/282837-7.stp
PCB/KiCadProj/KeyTestBoxLib/7PIN_SCREW_CONN/282837-7/Allegro/shdr7w100p0x508_1x7_3556x820x1000p.psm
PCB/KiCadProj/KeyTestBoxLib/7PIN_SCREW_CONN/282837-7/DEHDL/282837_7/chips/chips.prt
PCB/KiCadProj/KeyTestBoxLib/Diodos/ESDALC6V1-1U2/Allegro/esdalc6v11u2.psm
PCB/KiCadProj/KeyTestBoxLib/Diodos/ESDALC6V1-1U2/DEHDL/esdalc6v1_1u2/chips/chips.prt
PCB/KiCadProj/KeyTestBoxLib/Diodos/ESDALC6V1W5/Allegro/sot65p210x110-5n.psm
PCB/KiCadProj/KeyTestBoxLib/Diodos/ESDALC6V1W5/DEHDL/esdalc6v1w5/chips/chips.prt
PCB/KiCadProj/KeyTestBoxLib/Diodos/MMBZ27VCL/MMBZ27VCL-7-F/Allegro/sot96p240x120-3n.psm
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

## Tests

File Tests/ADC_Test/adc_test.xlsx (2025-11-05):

Fonte de Alimentação (V) | Multímetro (V) | Valor ADC (decimal) | Valor lido (V)
-12 | -12.06 | 155 | -12.055
-10 | -10.04 | 1499 | -10.039
-7.5 | -7.54 | 3167 | -7.537
5 | -5.02 | 4838 | -5.03
-2.5 | -2.51 | 6519 | -2.508
0 | 0.011 | 8204 | 0.018
2.5 | 2.51 | 9872 | 2.52
5 | 5.02 | 11553 | 5.042
7.5 | 7.54 | 13224 | 7.549
10 | 10.04 | 14892 | 10.051
12 | 12.06 | 16237 | 12.069

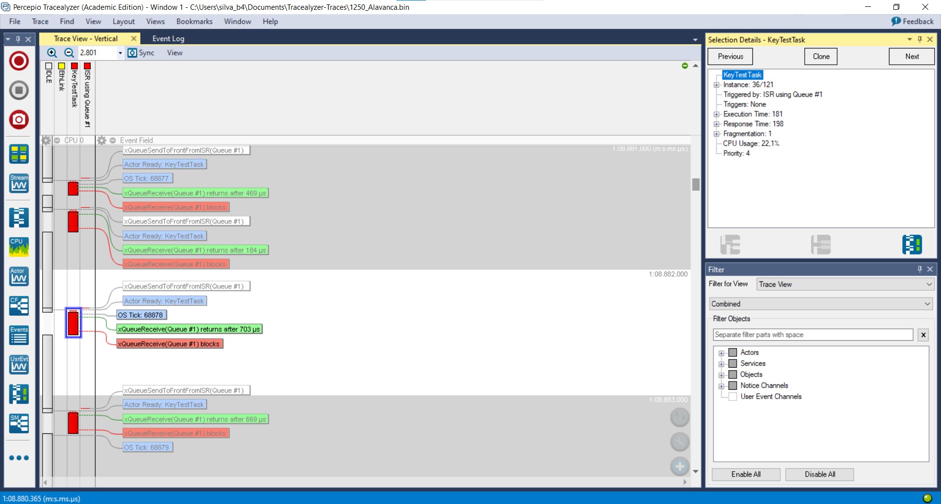
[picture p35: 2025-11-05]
Tests/Final Tests/Só Alavanca/1250_alavanca2.jpg

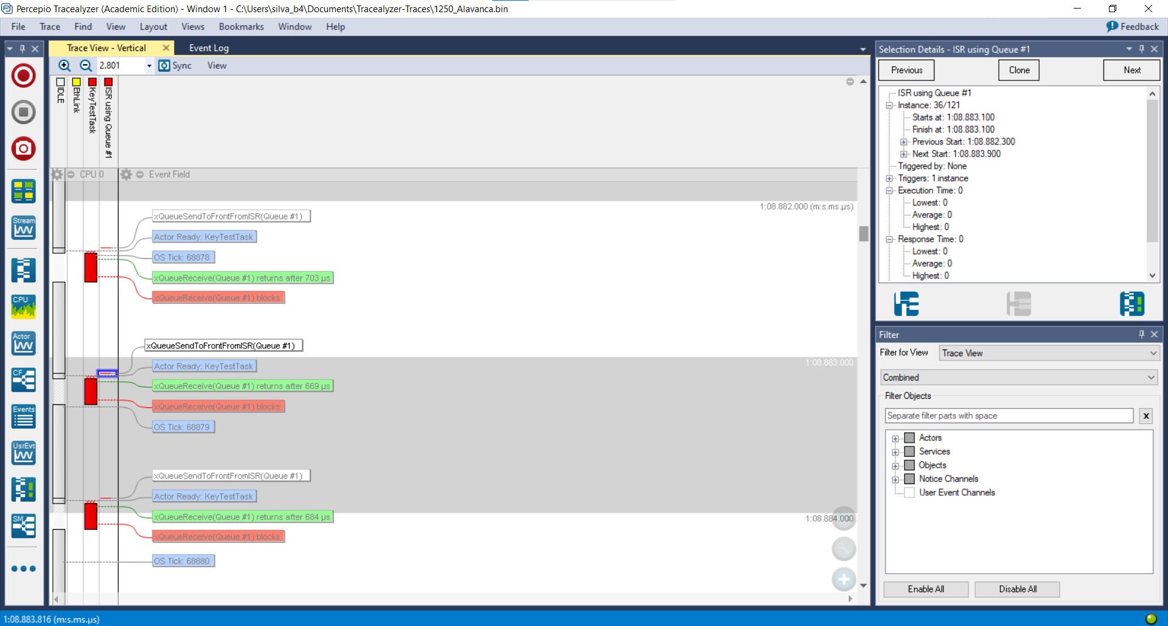
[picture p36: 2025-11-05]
Tests/Final Tests/Só Alavanca/1250_alavanca.jpg

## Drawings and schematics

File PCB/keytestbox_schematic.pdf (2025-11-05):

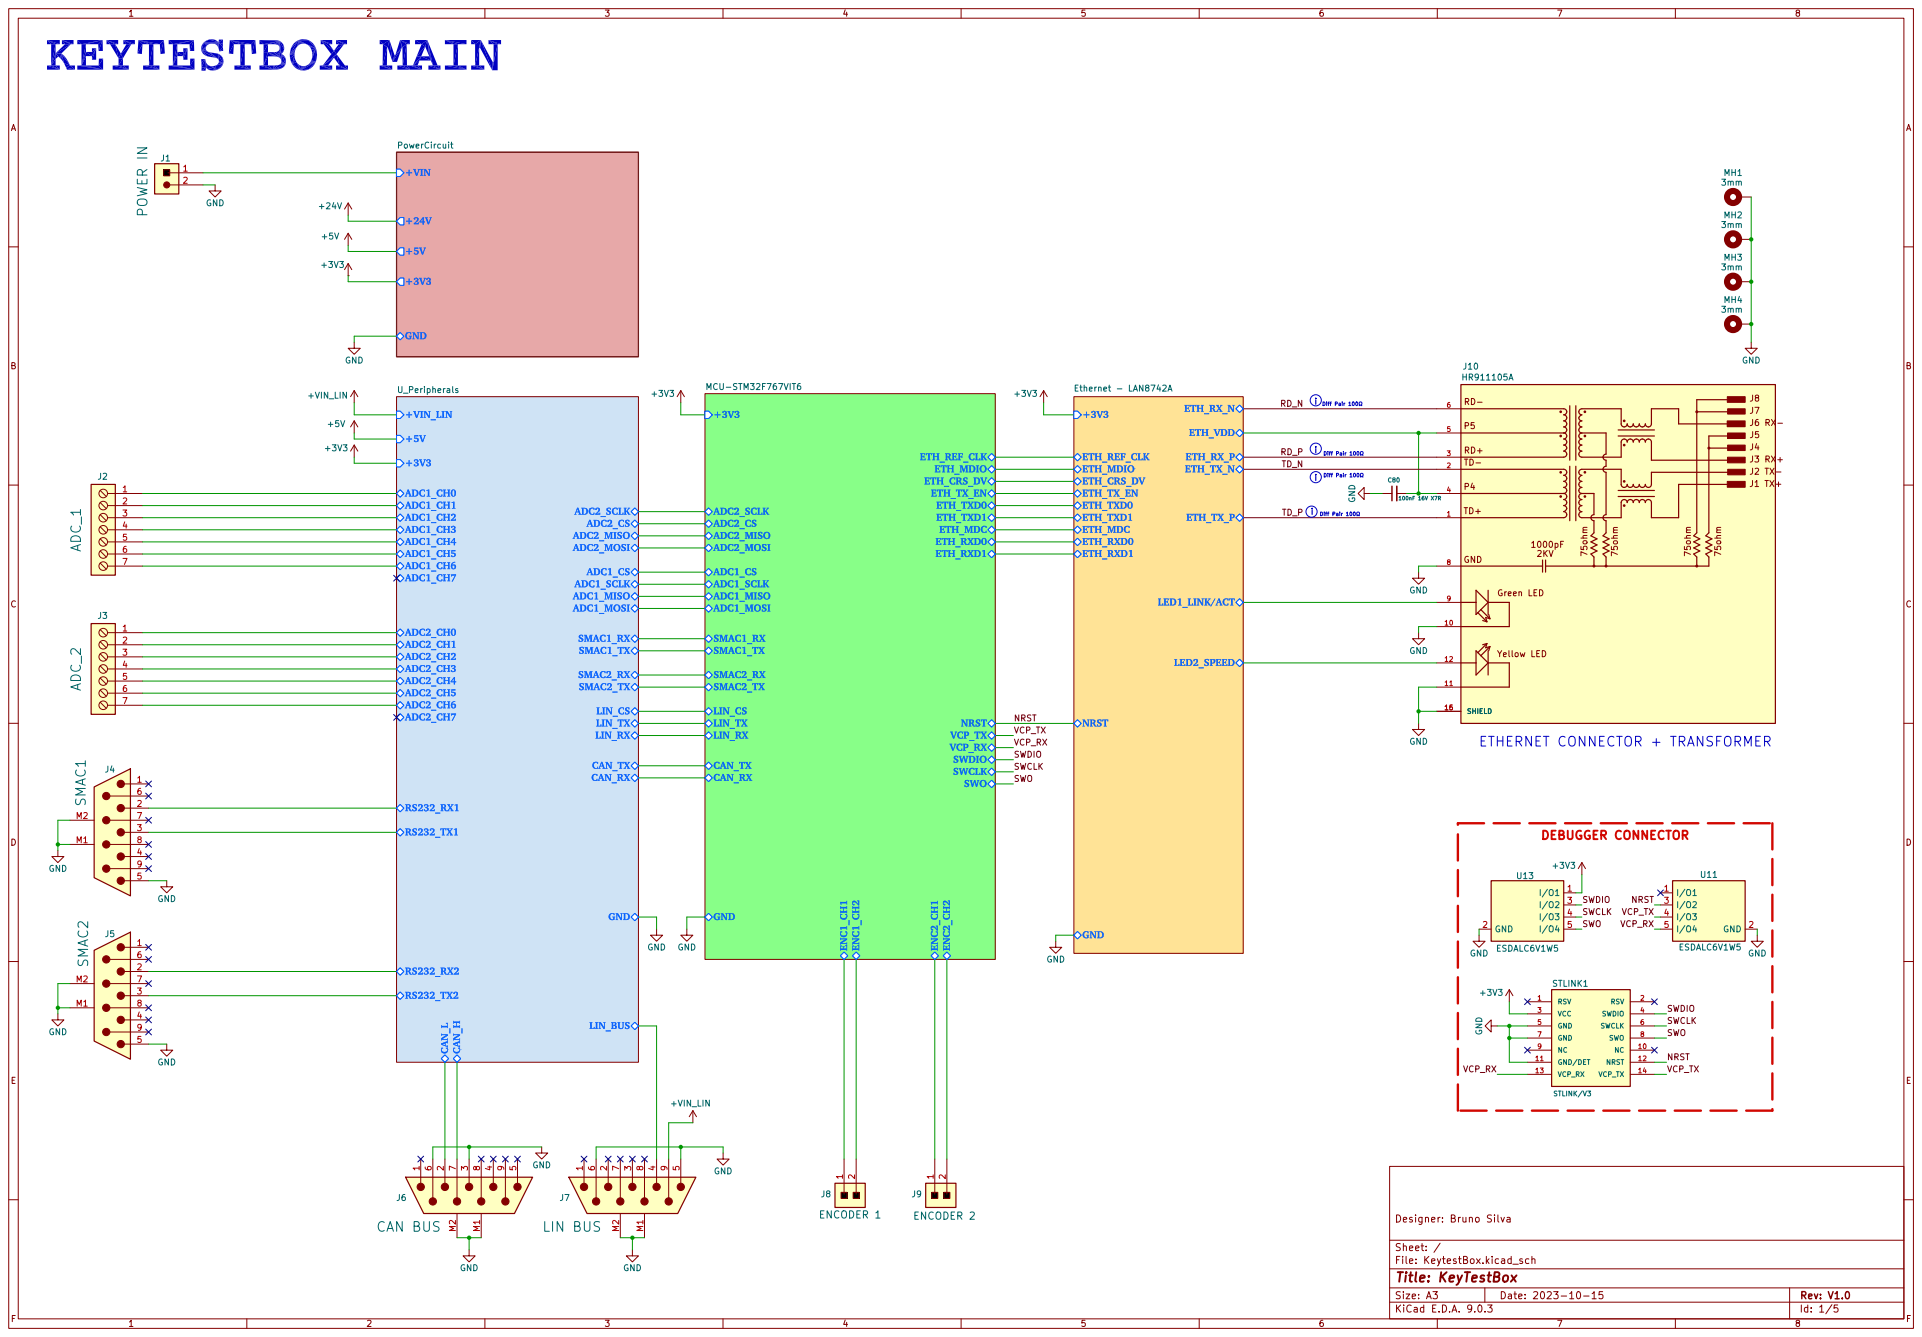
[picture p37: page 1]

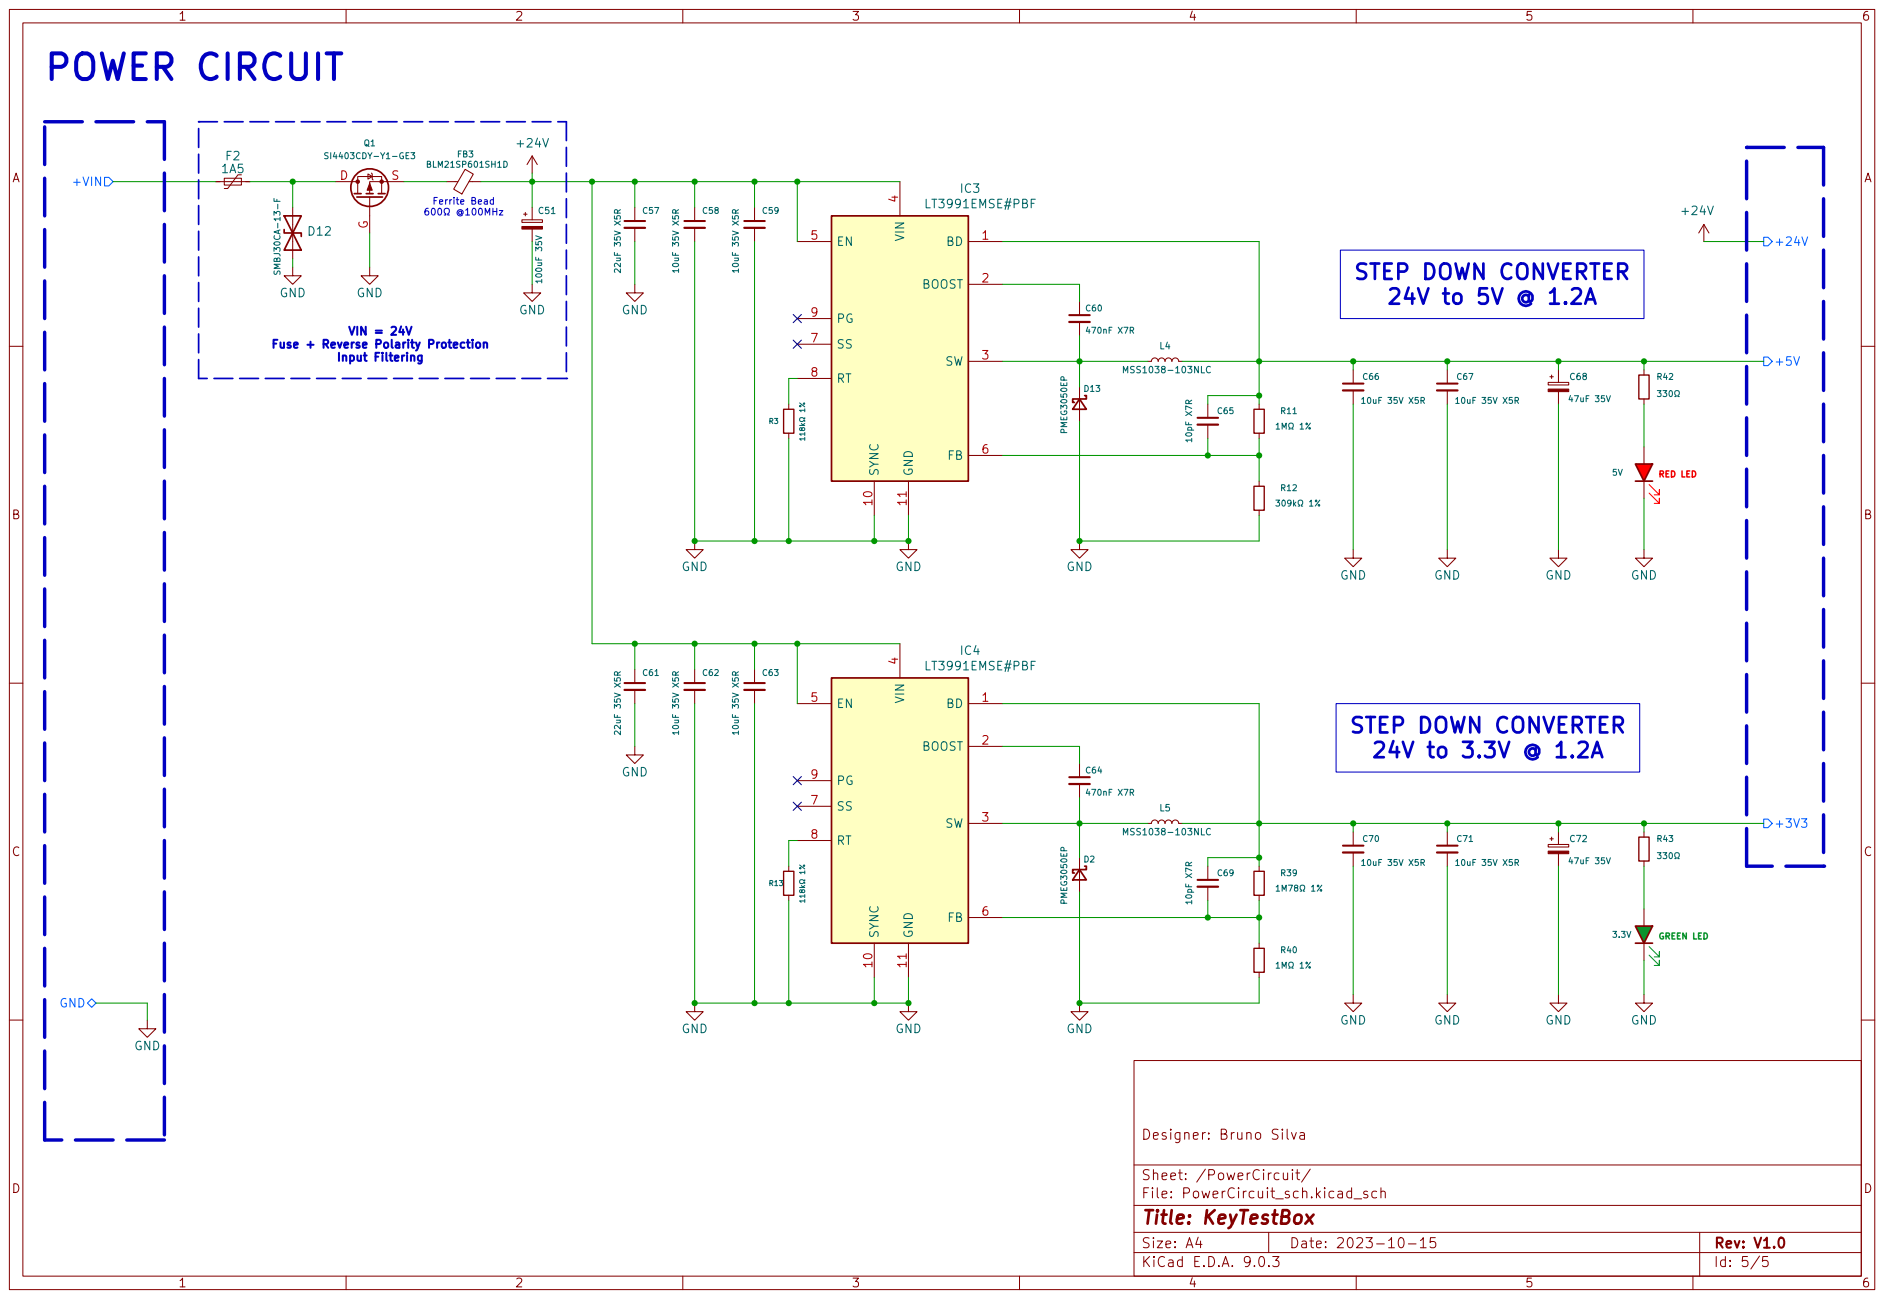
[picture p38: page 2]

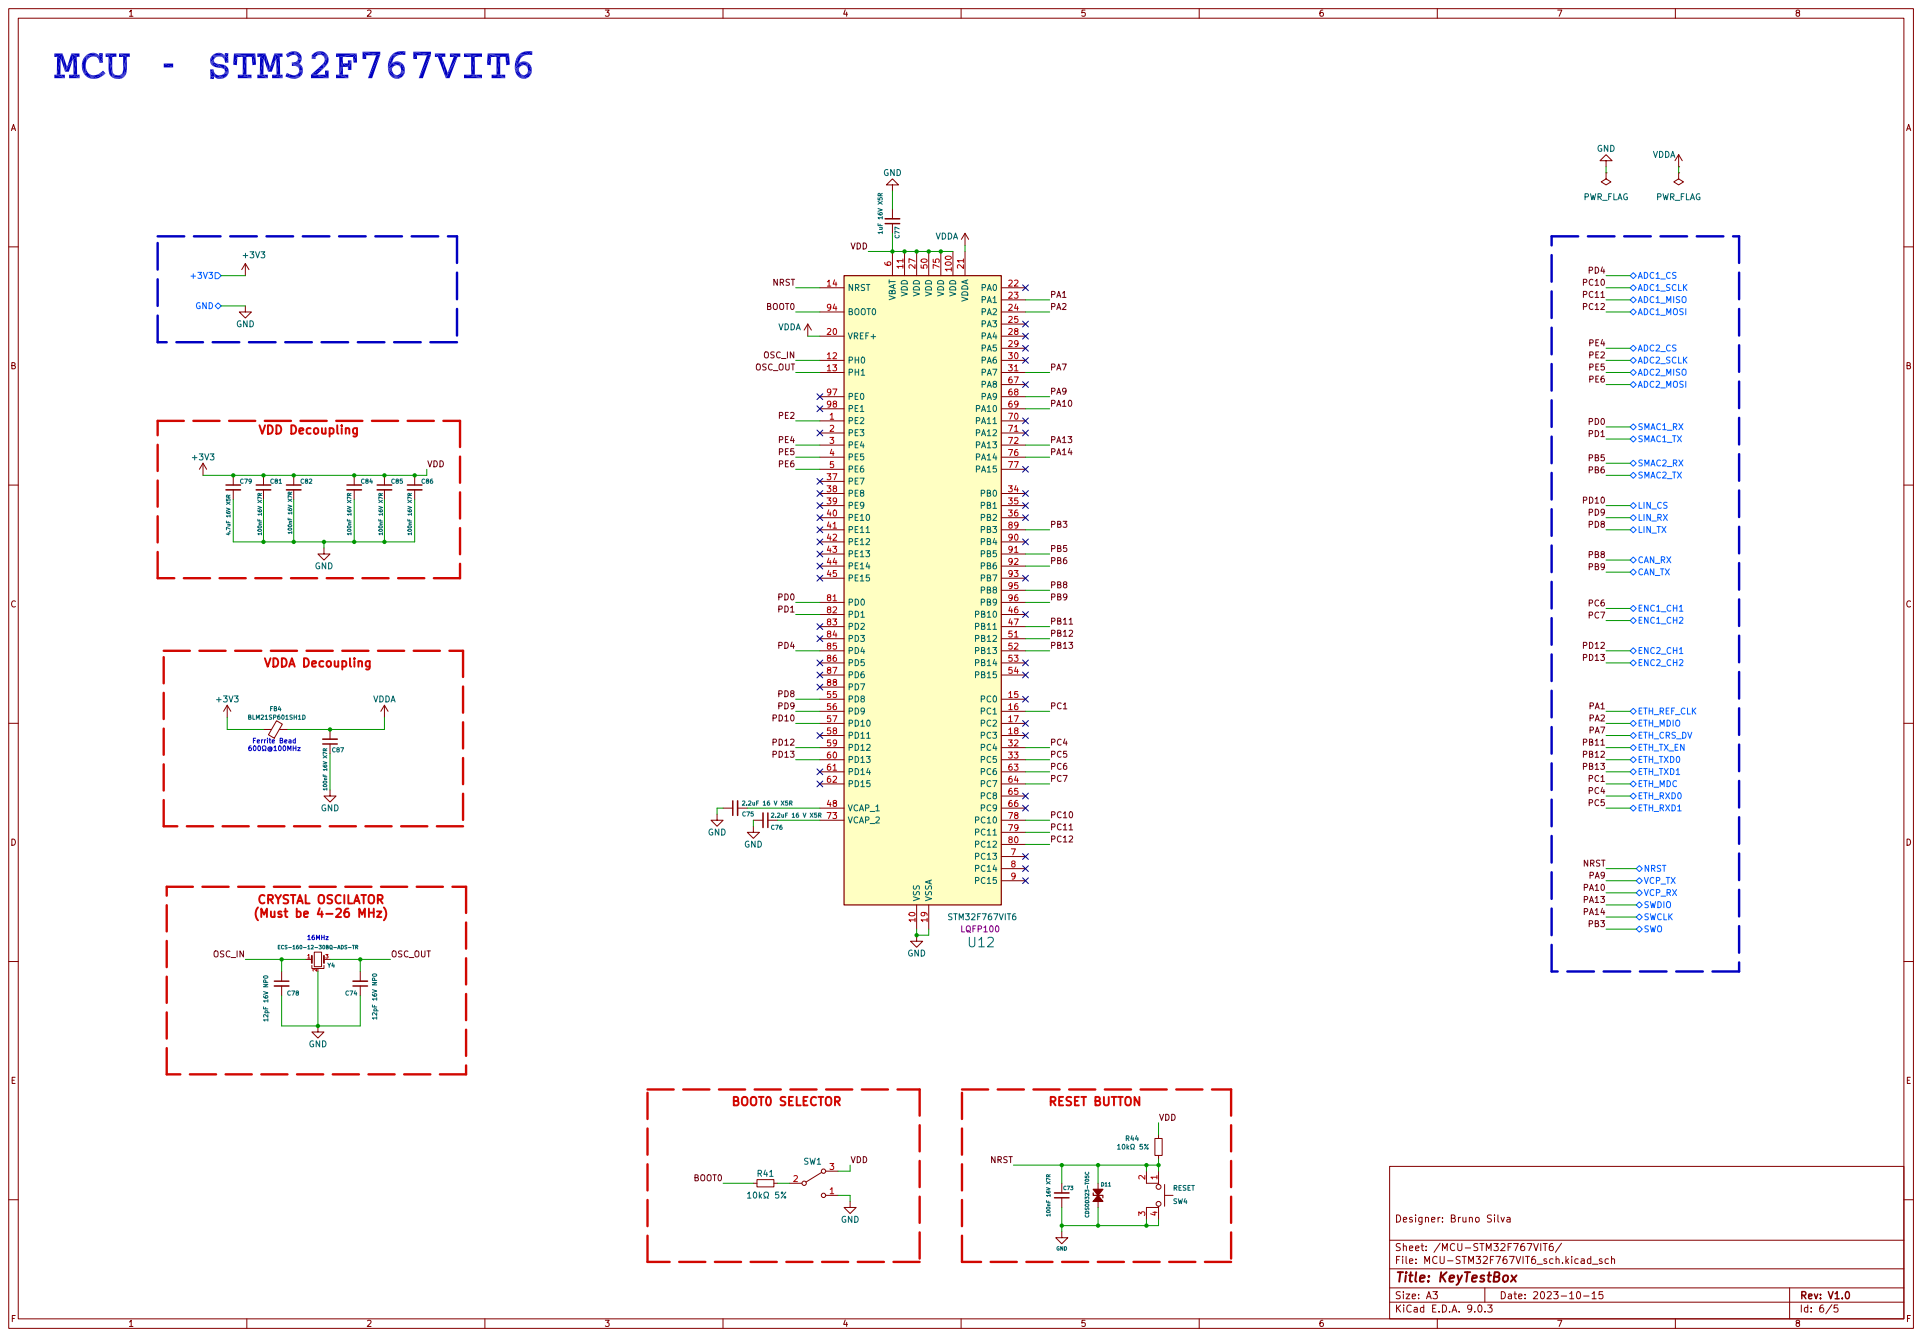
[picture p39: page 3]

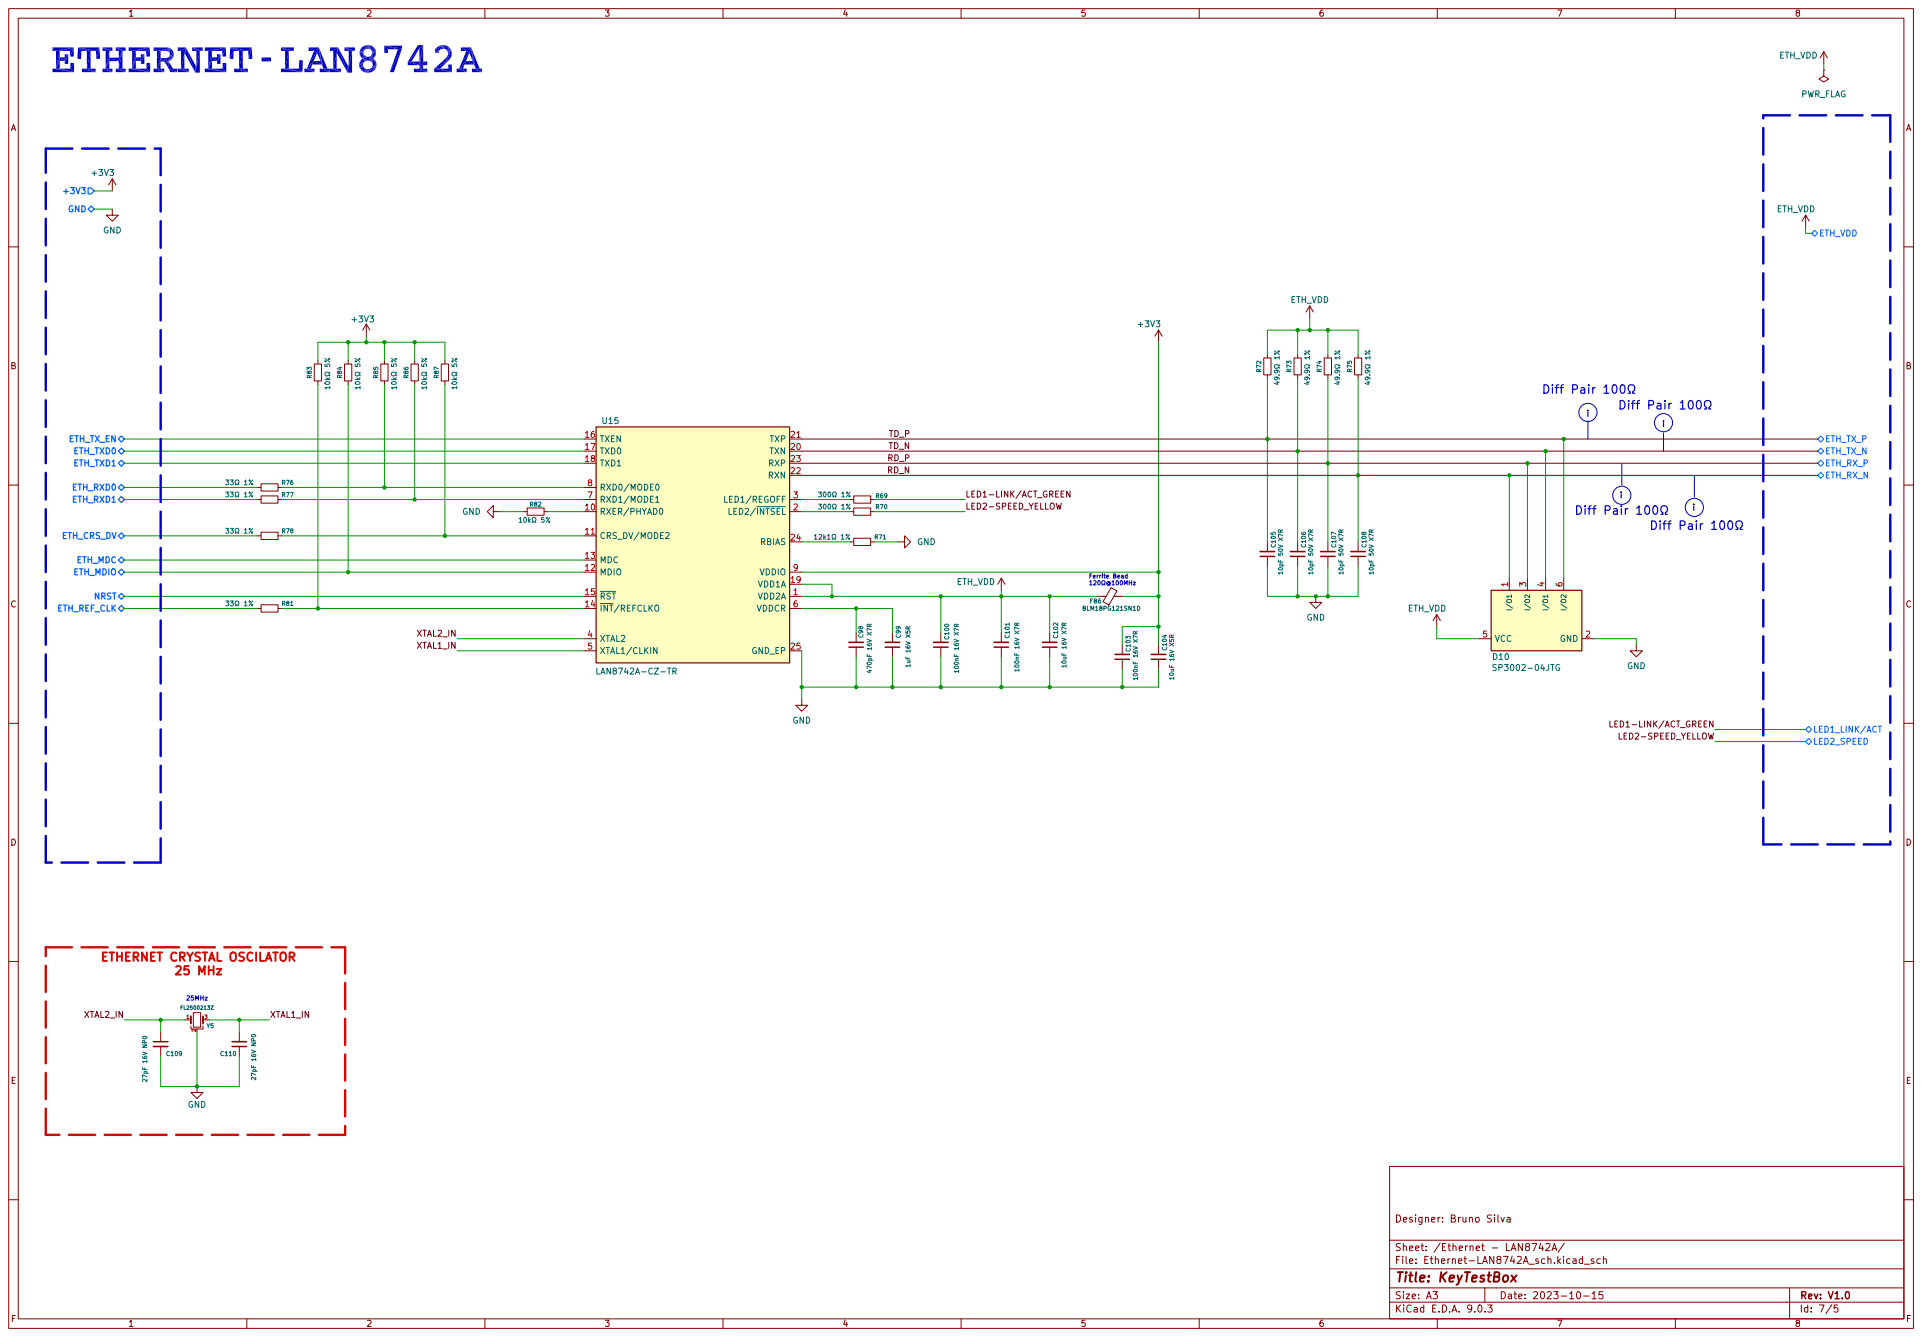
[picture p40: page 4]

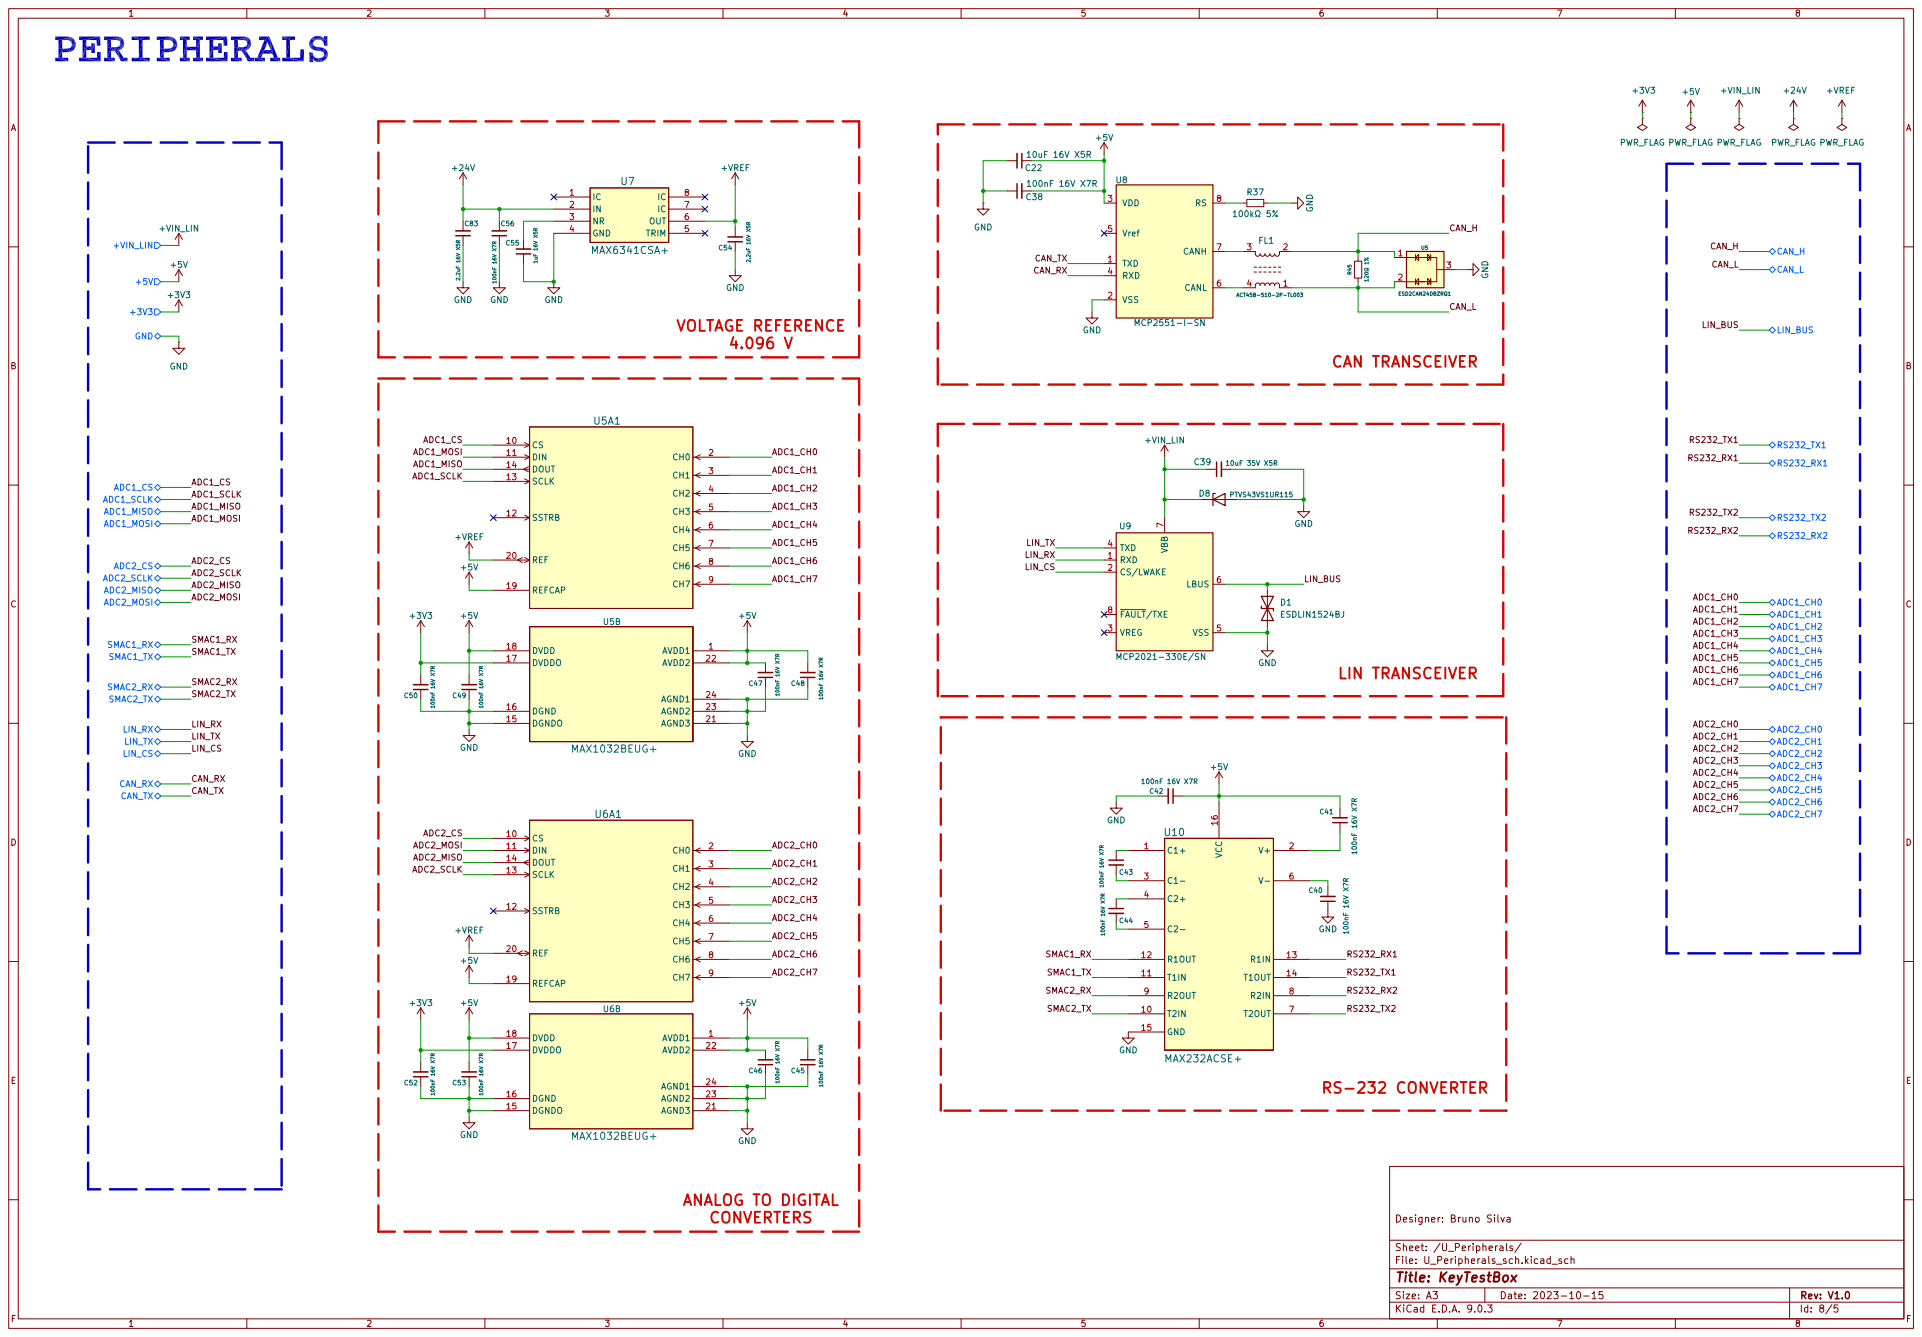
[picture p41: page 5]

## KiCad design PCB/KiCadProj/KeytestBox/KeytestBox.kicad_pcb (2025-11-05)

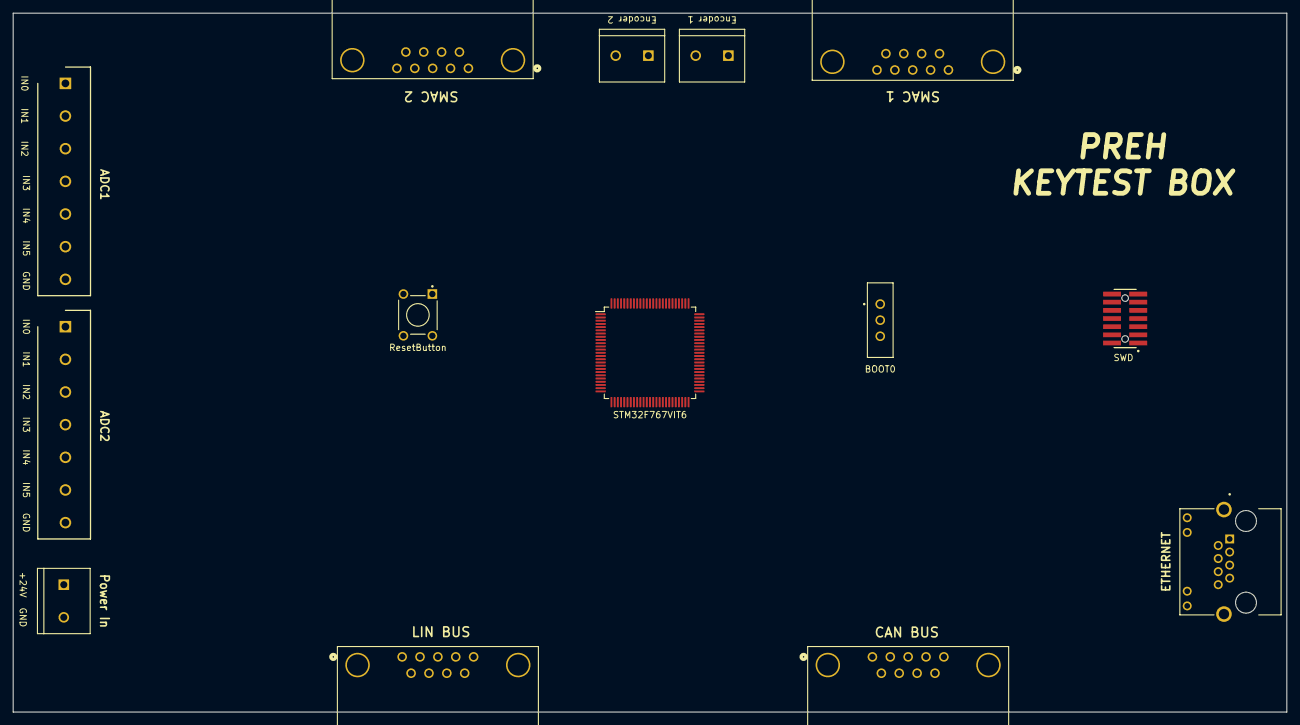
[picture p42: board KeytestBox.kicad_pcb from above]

Board: 2 copper layers, 198.1 x 108.7 mm, 14 parts (0 on the bottom side), 13 nets, no tracks yet.

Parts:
J1: Conn_02x07_Odd_Even; SAMTEC_FTSH-107-01-L-DV-K-A
J2, J11, J12: Screw_Terminal_01x02; TE_282837-2
J3: SCREW_TERM_1x7; SHDR7W100P0X508_1X7_3556X820X1000P
J4: RJHSE-5384; AMPHENOL_RJHSE-5384
J5, J6, J7, J8: DB9; CONN9X1_2286550-1_TEC
J9: Screw_Terminal_01x07; SHDR7W100P0X508_1X7_3556X820X1000P
SW1: SW_SPDT; SW_EG1218
SW2: ResetButton; SW_1825910-6-4
U1: STM32F767VIT6; LQFP-100_14x14mm_P0.5mm

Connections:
+24V: J2.1, J8.9
ENC1_CH1: J11.1, U1.63 (PC6)
ENC1_CH2: J11.2, U1.64 (PC7)
ENC2_CH1: J12.1, U1.59 (PD12)
ENC2_CH2: J12.2, U1.60 (PD13)
GND: J1.11, J2.2, J3.7, J5.5, J6.5, J7.3, J7.6, J8.5, J8.6, J9.7, SW1.3 (C), SW2.3 (K), SW2.4 (A), U1.10 (VSS), U1.19 (VSSA), U1.26 (VSS), U1.49 (VSS), U1.74 (VSS), U1.99 (VSS)
GNDPWR: J4.S1 (SHIELD1/SHIELD2), J4.S2 (SHIELD)
NRST: J1.12, SW2.1, SW2.2, U1.14 (NRST)
unnamed: J4.4 (NC), J4.5 (NC)
unnamed: J4.7 (NC), J4.8 (NC)
SD1_out: SW1.1 (A), U1.6 (VBAT), U1.11 (VDD), U1.20 (VREF+), U1.27 (VDD), U1.50 (VDD), U1.75 (VDD), U1.100 (VDD)
VCP_RX: J1.13, U1.69 (PA10)
VCP_TX: J1.14, U1.68 (PA9)

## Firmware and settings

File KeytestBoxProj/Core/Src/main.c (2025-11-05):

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
/* Includes ------------------------------------------------------------------*/
#include "main.h"
#include "cmsis_os.h"
#include "can.h"
#include "spi.h"
#include "tim.h"
#include "usart.h"
#include "gpio.h"

/* USER CODE BEGIN Includes */
#include "FreeRTOS.h"
#include "MAX1032.h"
#include "stdio.h"
#include "string.h"
#include "keytest.h"
/* USER CODE END Includes */


void SystemClock_Config(void);
static void MPU_Config(void);
void MX_FREERTOS_Init(void);
/* USER CODE BEGIN 0 */
extern osThreadId FirstTestTaskHandle;
extern osThreadId defaultTaskHandle;

extern xQueueHandle SmacOperationsQueue;

extern s_KeyTest* st_Keytest;

s_MAX1032 adc1;
s_MAX1032 adc2;

extern uint32_t sampleNUM;

/* USER CODE END 0 */

/**
  * @brief  The application entry point.
  * @retval int
  */
int main(void)
{
  /* MPU Configuration--------------------------------------------------------*/
  MPU_Config();

  /* MCU Configuration--------------------------------------------------------*/

  /* Reset of all peripherals, Initializes the Flash interface and the Systick. */
  HAL_Init();

  /* Configure the system clock */
  SystemClock_Config();

  /* USER CODE BEGIN SysInit */
 // Use Tracealyzer
  //xTraceInitialize();
  //xTraceEnable(TRC_START);

  /* USER CODE END SysInit */

  /* Initialize all configured peripherals */
  MX_GPIO_Init();
  MX_SPI3_Init();
  MX_SPI4_Init();
  MX_TIM3_Init();
  MX_TIM4_Init();
  MX_TIM13_Init();
  MX_UART4_Init();
  MX_UART5_Init();
  MX_USART3_UART_Init();
  MX_CAN1_Init();
  MX_TIM14_Init();
  /* Call init function for freertos objects (in freertos.c) */
  MX_FREERTOS_Init();

  /* Start scheduler */
  osKernelStart();
  /* We should never get here as control is now taken by the scheduler */
  /* Infinite loop */
  /* USER CODE BEGIN WHILE */
  while (1)
  {
	/* We should never get here as control is now taken by the scheduler */
    /* USER CODE END WHILE */

    /* USER CODE BEGIN 3 */

  }
  /* USER CODE END 3 */
}

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
/* MPU Configuration */

void MPU_Config(void)
{
  MPU_Region_InitTypeDef MPU_InitStruct = {0};

  /* Disables the MPU */
  HAL_MPU_Disable();

  /** Initializes and configures the Region and the memory to be protected
  */
  MPU_InitStruct.Enable = MPU_REGION_ENABLE;
  MPU_InitStruct.Number = MPU_REGION_NUMBER0;
  MPU_InitStruct.BaseAddress = 0x0;
  MPU_InitStruct.Size = MPU_REGION_SIZE_4GB;
  MPU_InitStruct.SubRegionDisable = 0x87;
  MPU_InitStruct.TypeExtField = MPU_TEX_LEVEL0;
  MPU_InitStruct.AccessPermission = MPU_REGION_NO_ACCESS;
  MPU_InitStruct.DisableExec = MPU_INSTRUCTION_ACCESS_DISABLE;
  MPU_InitStruct.IsShareable = MPU_ACCESS_SHAREABLE;
  MPU_InitStruct.IsCacheable = MPU_ACCESS_NOT_CACHEABLE;
  MPU_InitStruct.IsBufferable = MPU_ACCESS_NOT_BUFFERABLE;

  HAL_MPU_ConfigRegion(&MPU_InitStruct);
  /* Enables the MPU */
  HAL_MPU_Enable(MPU_PRIVILEGED_DEFAULT);

}

/**
  * @brief  Period elapsed callback in non blocking mode
  * @note   This function is called  when TIM1 interrupt took place, inside
  * HAL_TIM_IRQHandler(). It makes a direct call to HAL_IncTick() to increment
  * a global variable "uwTick" used as application time base.
  * @param  htim : TIM handle
  * @retval None
  */
void HAL_TIM_PeriodElapsedCallback(TIM_HandleTypeDef *htim)
{
  /* USER CODE BEGIN Callback 0 */
  uint8_t operation = OP_TEST_SAMPLE;
  BaseType_t pxHigherPriorityTaskWoken = pdFALSE;
  /* USER CODE END Callback 0 */
  if (htim->Instance == TIM1) {
    HAL_IncTick();
  }
  /* USER CODE BEGIN Callback 1 */
  else
  if(htim->Instance == st_Keytest->FreqTimer->Instance)  //nao pode comparar isto ainda
  {
	  //Deactivate Can Notification so that it doesnt occur during the Sample Operation
	  if(st_Keytest->UUT_Protocol == CAN_PROTOCOL)
	  {
		  if(st_Keytest->isCanFIFO0_Active)
			  HAL_CAN_DeactivateNotification(st_Keytest->CanPort, CAN_IT_RX_FIFO0_MSG_PENDING);
		  if(st_Keytest->isCanFIFO1_Active)
			  HAL_CAN_DeactivateNotification(st_Keytest->CanPort, CAN_IT_RX_FIFO1_MSG_PENDING);
	  }
	  //KEYTEST 1 Sample Time Elapsed
  	  //Send Test Sample Operation to Queue of KeytestTask
	  sampleNUM++;
	  xQueueSendToFrontFromISR(SmacOperationsQueue, &operation, &pxHigherPriorityTaskWoken);
  	  portYIELD_FROM_ISR(pxHigherPriorityTaskWoken);
  }
  /* USER CODE END Callback 1 */
}

/**
  * @brief  This function is executed in case of error occurrence.
  * @retval None
  */
void Error_Handler(void)
{
  /* USER CODE BEGIN Error_Handler_Debug */
  /* User can add his own implementation to report the HAL error return state */
  __disable_irq();
  while (1)
  {
  }
  /* USER CODE END Error_Handler_Debug */
}

#ifdef  USE_FULL_ASSERT
/**
  * @brief  Reports the name of the source file and the source line number
  *         where the assert_param error has occurred.
  * @param  file: pointer to the source file name
  * @param  line: assert_param error line source number
  * @retval None
  */
void assert_failed(uint8_t *file, uint32_t line)
{
  /* USER CODE BEGIN 6 */
  /* User can add his own implementation to report the file name and line number,
     ex: printf("Wrong parameters value: file %s on line %d\r\n", file, line) */
  /* USER CODE END 6 */
}
#endif /* USE_FULL_ASSERT */

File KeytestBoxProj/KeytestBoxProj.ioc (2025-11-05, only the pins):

Mcu.UserName=STM32F767VITx
PA1.Signal=ETH_REF_CLK
PA13.Signal=SYS_JTMS-SWDIO
PA14.Signal=SYS_JTCK-SWCLK
PA2.Signal=ETH_MDIO
PA7.Signal=ETH_CRS_DV
PB11.Signal=ETH_TX_EN
PB12.Signal=ETH_TXD0
PB13.Signal=ETH_TXD1
PB3.Signal=SYS_JTDO-SWO
PB5.GPIO_Label=SMAC2_RX
PB5.Signal=UART5_RX
PB6.GPIO_Label=SMAC2_TX
PB6.Signal=UART5_TX
PB8.Signal=CAN1_RX
PB9.Signal=CAN1_TX
PC1.Signal=ETH_MDC
PC10.GPIO_Label=ADC1_SCK
PC10.Signal=SPI3_SCK
PC11.GPIO_Label=ADC1_MISO
PC11.Signal=SPI3_MISO
PC12.GPIO_Label=ADC1_MOSI
PC12.Signal=SPI3_MOSI
PC4.Signal=ETH_RXD0
PC5.Signal=ETH_RXD1
PC6.GPIO_Label=ENC2_CH1
PC6.Signal=S_TIM3_CH1
PC7.GPIO_Label=ENC2_CH2
PC7.Signal=S_TIM3_CH2
PD0.GPIO_Label=SMAC1_RX
PD0.Signal=UART4_RX
PD1.GPIO_Label=SMAC1_TX
PD1.Signal=UART4_TX
PD12.GPIO_Label=ENC1_CH1
PD12.Signal=S_TIM4_CH1
PD13.GPIO_Label=ENC1_CH2
PD13.Signal=S_TIM4_CH2
PD4.Signal=GPIO_Output
PD8.GPIO_Label=LIN_TX
PD8.Signal=USART3_TX
PD9.GPIO_Label=LIN_RX
PD9.Signal=USART3_RX
PE2.GPIO_Label=ADC2_SCK
PE2.Signal=SPI4_SCK
PE4.Signal=GPIO_Output
PE5.GPIO_Label=ADC2_MISO
PE5.Signal=SPI4_MISO
PE6.GPIO_Label=ADC2_MOSI
PE6.Signal=SPI4_MOSI
PH0/OSC_IN.Signal=RCC_OSC_IN
PH1/OSC_OUT.Signal=RCC_OSC_OUT

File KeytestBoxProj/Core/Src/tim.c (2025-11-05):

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
/* Includes ------------------------------------------------------------------*/
#include "tim.h"

TIM_HandleTypeDef htim3;
TIM_HandleTypeDef htim4;
TIM_HandleTypeDef htim13;
TIM_HandleTypeDef htim14;

/* TIM3 init function */
void MX_TIM3_Init(void)
{

  TIM_Encoder_InitTypeDef sConfig = {0};
  TIM_MasterConfigTypeDef sMasterConfig = {0};

  htim3.Instance = TIM3;
  htim3.Init.Prescaler = 0;
  htim3.Init.CounterMode = TIM_COUNTERMODE_UP;
  htim3.Init.Period = 65535;
  htim3.Init.ClockDivision = TIM_CLOCKDIVISION_DIV1;
  htim3.Init.AutoReloadPreload = TIM_AUTORELOAD_PRELOAD_ENABLE;
  sConfig.EncoderMode = TIM_ENCODERMODE_TI12;
  sConfig.IC1Polarity = TIM_ICPOLARITY_RISING;
  sConfig.IC1Selection = TIM_ICSELECTION_DIRECTTI;
  sConfig.IC1Prescaler = TIM_ICPSC_DIV1;
  sConfig.IC1Filter = 10;
  sConfig.IC2Polarity = TIM_ICPOLARITY_RISING;
  sConfig.IC2Selection = TIM_ICSELECTION_DIRECTTI;
  sConfig.IC2Prescaler = TIM_ICPSC_DIV1;
  sConfig.IC2Filter = 10;
  if (HAL_TIM_Encoder_Init(&htim3, &sConfig) != HAL_OK)
  {
    Error_Handler();
  }
  sMasterConfig.MasterOutputTrigger = TIM_TRGO_RESET;
  sMasterConfig.MasterSlaveMode = TIM_MASTERSLAVEMODE_DISABLE;
  if (HAL_TIMEx_MasterConfigSynchronization(&htim3, &sMasterConfig) != HAL_OK)
  {
    Error_Handler();
  }
}
/* TIM4 init function */
void MX_TIM4_Init(void)
{

  TIM_Encoder_InitTypeDef sConfig = {0};
  TIM_MasterConfigTypeDef sMasterConfig = {0};

  htim4.Instance = TIM4;
  htim4.Init.Prescaler = 0;
  htim4.Init.CounterMode = TIM_COUNTERMODE_UP;
  htim4.Init.Period = 65535;
  htim4.Init.ClockDivision = TIM_CLOCKDIVISION_DIV1;
  htim4.Init.AutoReloadPreload = TIM_AUTORELOAD_PRELOAD_ENABLE;
  sConfig.EncoderMode = TIM_ENCODERMODE_TI12;
  sConfig.IC1Polarity = TIM_ICPOLARITY_RISING;
  sConfig.IC1Selection = TIM_ICSELECTION_DIRECTTI;
  sConfig.IC1Prescaler = TIM_ICPSC_DIV1;
  sConfig.IC1Filter = 10;
  sConfig.IC2Polarity = TIM_ICPOLARITY_RISING;
  sConfig.IC2Selection = TIM_ICSELECTION_DIRECTTI;
  sConfig.IC2Prescaler = TIM_ICPSC_DIV1;
  sConfig.IC2Filter = 10;
  if (HAL_TIM_Encoder_Init(&htim4, &sConfig) != HAL_OK)
  {
    Error_Handler();
  }
  sMasterConfig.MasterOutputTrigger = TIM_TRGO_RESET;
  sMasterConfig.MasterSlaveMode = TIM_MASTERSLAVEMODE_DISABLE;
  if (HAL_TIMEx_MasterConfigSynchronization(&htim4, &sMasterConfig) != HAL_OK)
  {
    Error_Handler();
  }
}
/* TIM13 init function */
void MX_TIM13_Init(void)
{

  htim13.Instance = TIM13;
  htim13.Init.Prescaler = 0;
  htim13.Init.CounterMode = TIM_COUNTERMODE_UP;
  htim13.Init.Period = 64799;
  htim13.Init.ClockDivision = TIM_CLOCKDIVISION_DIV1;
  htim13.Init.AutoReloadPreload = TIM_AUTORELOAD_PRELOAD_ENABLE;
  if (HAL_TIM_Base_Init(&htim13) != HAL_OK)
  {
    Error_Handler();
  }
}
/* TIM14 init function */
void MX_TIM14_Init(void)
{

  htim14.Instance = TIM14;
  htim14.Init.Prescaler = 0;
  htim14.Init.CounterMode = TIM_COUNTERMODE_UP;
  htim14.Init.Period = 65535;
  htim14.Init.ClockDivision = TIM_CLOCKDIVISION_DIV1;
  htim14.Init.AutoReloadPreload = TIM_AUTORELOAD_PRELOAD_DISABLE;
  if (HAL_TIM_Base_Init(&htim14) != HAL_OK)
  {
    Error_Handler();
  }
}

void HAL_TIM_Encoder_MspInit(TIM_HandleTypeDef* tim_encoderHandle)
{

  GPIO_InitTypeDef GPIO_InitStruct = {0};
  if(tim_encoderHandle->Instance==TIM3)
  {
    /* TIM3 clock enable */
    __HAL_RCC_TIM3_CLK_ENABLE();

    __HAL_RCC_GPIOC_CLK_ENABLE();
    /**TIM3 GPIO Configuration
    PC6     ------> TIM3_CH1
    PC7     ------> TIM3_CH2
    */
    GPIO_InitStruct.Pin = ENC2_CH1_Pin|ENC2_CH2_Pin;
    GPIO_InitStruct.Mode = GPIO_MODE_AF_PP;
    GPIO_InitStruct.Pull = GPIO_NOPULL;
    GPIO_InitStruct.Speed = GPIO_SPEED_FREQ_LOW;
    GPIO_InitStruct.Alternate = GPIO_AF2_TIM3;
    HAL_GPIO_Init(GPIOC, &GPIO_InitStruct);

  }
  else if(tim_encoderHandle->Instance==TIM4)
  {
    /* TIM4 clock enable */
    __HAL_RCC_TIM4_CLK_ENABLE();

    __HAL_RCC_GPIOD_CLK_ENABLE();
    /**TIM4 GPIO Configuration
    PD12     ------> TIM4_CH1
    PD13     ------> TIM4_CH2
    */
    GPIO_InitStruct.Pin = ENC1_CH1_Pin|ENC1_CH2_Pin;
    GPIO_InitStruct.Mode = GPIO_MODE_AF_PP;
    GPIO_InitStruct.Pull = GPIO_NOPULL;
    GPIO_InitStruct.Speed = GPIO_SPEED_FREQ_LOW;
    GPIO_InitStruct.Alternate = GPIO_AF2_TIM4;
    HAL_GPIO_Init(GPIOD, &GPIO_InitStruct);

  }
}

void HAL_TIM_Base_MspInit(TIM_HandleTypeDef* tim_baseHandle)
{

  if(tim_baseHandle->Instance==TIM13)
  {
    /* TIM13 clock enable */
    __HAL_RCC_TIM13_CLK_ENABLE();

    /* TIM13 interrupt Init */
    HAL_NVIC_SetPriority(TIM8_UP_TIM13_IRQn, 5, 0);
    HAL_NVIC_EnableIRQ(TIM8_UP_TIM13_IRQn);
  }
  else if(tim_baseHandle->Instance==TIM14)
  {
    /* TIM14 clock enable */
    __HAL_RCC_TIM14_CLK_ENABLE();
  }
}

void HAL_TIM_Encoder_MspDeInit(TIM_HandleTypeDef* tim_encoderHandle)
{

  if(tim_encoderHandle->Instance==TIM3)
  {
    /* Peripheral clock disable */
    __HAL_RCC_TIM3_CLK_DISABLE();

    /**TIM3 GPIO Configuration
    PC6     ------> TIM3_CH1
    PC7     ------> TIM3_CH2
    */
    HAL_GPIO_DeInit(GPIOC, ENC2_CH1_Pin|ENC2_CH2_Pin);

  }
  else if(tim_encoderHandle->Instance==TIM4)
  {
    /* Peripheral clock disable */
    __HAL_RCC_TIM4_CLK_DISABLE();

    /**TIM4 GPIO Configuration
    PD12     ------> TIM4_CH1
    PD13     ------> TIM4_CH2
    */
    HAL_GPIO_DeInit(GPIOD, ENC1_CH1_Pin|ENC1_CH2_Pin);

  }
}

void HAL_TIM_Base_MspDeInit(TIM_HandleTypeDef* tim_baseHandle)
{

  if(tim_baseHandle->Instance==TIM13)
  {
    /* Peripheral clock disable */
    __HAL_RCC_TIM13_CLK_DISABLE();

    /* TIM13 interrupt Deinit */
    HAL_NVIC_DisableIRQ(TIM8_UP_TIM13_IRQn);
  }
  else if(tim_baseHandle->Instance==TIM14)
  {
    /* Peripheral clock disable */
    __HAL_RCC_TIM14_CLK_DISABLE();
  }
}



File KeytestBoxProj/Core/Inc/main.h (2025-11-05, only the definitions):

#define ADC2_SCK_Pin GPIO_PIN_2
#define ADC2_SCK_GPIO_Port GPIOE
#define ADC2_MISO_Pin GPIO_PIN_5
#define ADC2_MISO_GPIO_Port GPIOE
#define ADC2_MOSI_Pin GPIO_PIN_6
#define ADC2_MOSI_GPIO_Port GPIOE
#define LIN_TX_Pin GPIO_PIN_8
#define LIN_TX_GPIO_Port GPIOD
#define LIN_RX_Pin GPIO_PIN_9
#define LIN_RX_GPIO_Port GPIOD
#define ENC1_CH1_Pin GPIO_PIN_12
#define ENC1_CH1_GPIO_Port GPIOD
#define ENC1_CH2_Pin GPIO_PIN_13
#define ENC1_CH2_GPIO_Port GPIOD
#define ENC2_CH1_Pin GPIO_PIN_6
#define ENC2_CH1_GPIO_Port GPIOC
#define ENC2_CH2_Pin GPIO_PIN_7
#define ENC2_CH2_GPIO_Port GPIOC
#define ADC1_SCK_Pin GPIO_PIN_10
#define ADC1_SCK_GPIO_Port GPIOC
#define ADC1_MISO_Pin GPIO_PIN_11
#define ADC1_MISO_GPIO_Port GPIOC
#define ADC1_MOSI_Pin GPIO_PIN_12
#define ADC1_MOSI_GPIO_Port GPIOC
#define SMAC1_RX_Pin GPIO_PIN_0
#define SMAC1_RX_GPIO_Port GPIOD
#define SMAC1_TX_Pin GPIO_PIN_1
#define SMAC1_TX_GPIO_Port GPIOD
#define SMAC2_RX_Pin GPIO_PIN_5
#define SMAC2_RX_GPIO_Port GPIOB
#define SMAC2_TX_Pin GPIO_PIN_6
#define SMAC2_TX_GPIO_Port GPIOB

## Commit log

2025-11-05 add project files
    [1825910-6.step, 21-0041B_8_MXM.step, 21-0041_S161_MXM.step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]
2025-11-08 Revise test description for gear shift lever
    Updated the description of the primary test target and clarified the testing conditions and results.

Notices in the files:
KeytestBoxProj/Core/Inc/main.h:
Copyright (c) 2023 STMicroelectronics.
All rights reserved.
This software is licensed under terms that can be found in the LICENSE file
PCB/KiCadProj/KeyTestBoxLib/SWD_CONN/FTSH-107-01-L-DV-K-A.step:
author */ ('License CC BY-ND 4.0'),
